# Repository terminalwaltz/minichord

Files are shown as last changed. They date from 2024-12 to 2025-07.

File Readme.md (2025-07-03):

# minichord 

This repository contains the source file both for the minichord itself and its documentation. 

Watch the video (https://www.youtube.com/watch?v=66Gu4NNnHgA)

To be informed about the project, please subscribe to [the newsletter](https://buttondown.com/BenjaminPoilve).

* [#1 project update](https://buttondown.com/BenjaminPoilve/archive/minichord-update-1/) 
* [#2 project update](https://buttondown.com/BenjaminPoilve/archive/minichord-update-2/) 
* [#3 project update and pre-order link](https://buttondown.com/BenjaminPoilve/archive/minichord-update-3/) 
* [#4 project update](https://buttondown.com/BenjaminPoilve/archive/minichord-update-4/) 
* [#5 project update](https://buttondown.com/BenjaminPoilve/archive/minichord-update-5/) 

## Documentation 

The best way to get to know this project is to visit the [minichord website](https://minichord.com/) which contains the documentation of the project. 

In particular it contains:

- the [user manual of the minichord](https://minichord.com/user_manual/)
- the [assembly guide of the minichord](https://minichord.com/assembly/)

This documentation is build with mkdocs and the relevant source and build script is available in the [documentation folder](https://github.com/BenjaminPoilve/MiniChord/tree/main/documentation).

## Hardware 

The hardware folder contains the necessary ressources to build a minichord. 

All hardware is provided under a Creative Commons Attribution-NonCommercial 4.0 International Public
License (CC BY-NC 4.0). 

In particular it contains: 

- the [files necessary to manufacture the PCB](https://github.com/BenjaminPoilve/MiniChord/tree/main/hardware/PCB)
- the [full BOM of the project](https://github.com/BenjaminPoilve/MiniChord/tree/main/hardware/BOM)
- the [3D enclosure files](https://github.com/BenjaminPoilve/MiniChord/tree/main/hardware/3D/rendering)
- the [keycap routing files](https://github.com/BenjaminPoilve/MiniChord/tree/main/hardware/graphics)

## Firmware 

The firmware folder contains the project firmware and necessary programming ressources.

All software is provided under a 3-clause BSD License.

In particular it contains: 
- the [Hex firmware](https://github.com/BenjaminPoilve/MiniChord/blob/main/firmware/firmware.hex)
- the full [PlatformIO project](https://github.com/BenjaminPoilve/MiniChord/tree/main/firmware)
- the [minicontrol software](https://github.com/BenjaminPoilve/MiniChord/tree/main/firmware/minicontrol)

## Media 

Here is a list of available media related to the project (to be completed) :

- a technical video about [the minicontrol system](https://www.youtube.com/watch?v=h-6qkhU_WoA&t=933s)
- a short [audio demo of selected presets](https://minichord.com/ressources/audio_demo.mp3)
- a [review of the project by Hainbach](https://www.youtube.com/watch?v=zQC3umGRGbM)
- an [interview I gave for the launch of the project with SeeedStudio](https://www.youtube.com/watch?v=swZKdO71dLo)
- a [folder of videos from minichord users](https://github.com/BenjaminPoilve/minichord/tree/main/documentation/docs/ressources/video) 

## Contact 

For any information about the project, don't hesitate to write at info@minichord.com

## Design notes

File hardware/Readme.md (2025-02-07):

# Hardware  

This folder contains the necessary ressources to build a minichord. 

### Electronics

* [Main PCB schematics](https://github.com/BenjaminPoilve/MiniChord/blob/main/hardware/PCB/miniChord_main_PCB/MiniChord.pdf)
* [Main PCB Gerber file](https://github.com/BenjaminPoilve/MiniChord/tree/main/hardware/PCB/miniChord_main_PCB/gerber)
* [Touch zone PCB schematics](https://github.com/BenjaminPoilve/MiniChord/blob/main/hardware/PCB/touch%20zones/default%20touch%20PCB/touch_zone.pdf)
* [Touch zone PCB Gerber file](https://github.com/BenjaminPoilve/MiniChord/blob/main/hardware/PCB/touch%20zones/default%20touch%20PCB/gerber)
* [Template for custom touch zone](https://github.com/BenjaminPoilve/MiniChord/blob/main/hardware/PCB/touch%20zones/touch%20kicad%20template)

### BOM

* [Full BOM](https://github.com/BenjaminPoilve/MiniChord/blob/main/hardware/BOM/full_BOM.pdf)

### 3D files

* [Bottom shell](https://github.com/BenjaminPoilve/MiniChord/blob/main/hardware/3D/rendering/render_v9_bottom.scad.stl) 
* [Top shell](https://github.com/BenjaminPoilve/MiniChord/blob/main/hardware/3D/rendering/render_v9_top1_5.scad.stl)

### 2D files 

* [Key engraving](https://github.com/BenjaminPoilve/MiniChord/blob/main/hardware/graphics/key_engraving.svg)

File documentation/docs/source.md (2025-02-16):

# **Software** 

> All software is provided under a 3-clause BSD License

* [minicontrol software](https://github.com/BenjaminPoilve/MiniChord/tree/main/firmware/minicontrol)
* [Hex firmware](https://github.com/BenjaminPoilve/MiniChord/blob/main/firmware/firmware.hex)
* [PlatformIO project](https://github.com/BenjaminPoilve/MiniChord/tree/main/firmware)
* [Tutorial for PlatformIO Teensy usage](https://forum.pjrc.com/index.php?threads/tutorial-how-to-use-platformio-visual-code-studio-for-teensy.66674/)

<hr>

# **Hardware**

> All hardware is provided under a Creative Commons Attribution-NonCommercial 4.0 International Public
License (CC BY-NC 4.0)

## 3D files

* [Bottom shell](https://github.com/BenjaminPoilve/MiniChord/blob/main/hardware/3D/rendering/render_v11_bottom.scad.stl) 
* [Top shell](https://github.com/BenjaminPoilve/MiniChord/blob/main/hardware/3D/rendering/render_v11_top.scad.stl)

## 2D files 

* [Key engraving](https://github.com/BenjaminPoilve/MiniChord/blob/main/hardware/graphics/key_engraving.svg)

## Electronics

* [Full BOM](https://github.com/BenjaminPoilve/MiniChord/blob/main/hardware/BOM/full_BOM.pdf)
* [Main PCB schematics](https://github.com/BenjaminPoilve/MiniChord/blob/main/hardware/PCB/miniChord_main_PCB/MiniChord.pdf)
* [Main PCB Gerber file](https://github.com/BenjaminPoilve/MiniChord/tree/main/hardware/PCB/miniChord_main_PCB/gerber)
* [Touch zone PCB schematics](https://github.com/BenjaminPoilve/MiniChord/blob/main/hardware/PCB/touch%20zones/default%20touch%20PCB/touch_zone.pdf)
* [Touch zone PCB Gerber file](https://github.com/BenjaminPoilve/MiniChord/tree/main/hardware/PCB/touch%20zones/default%20touch%20PCB/gerber)

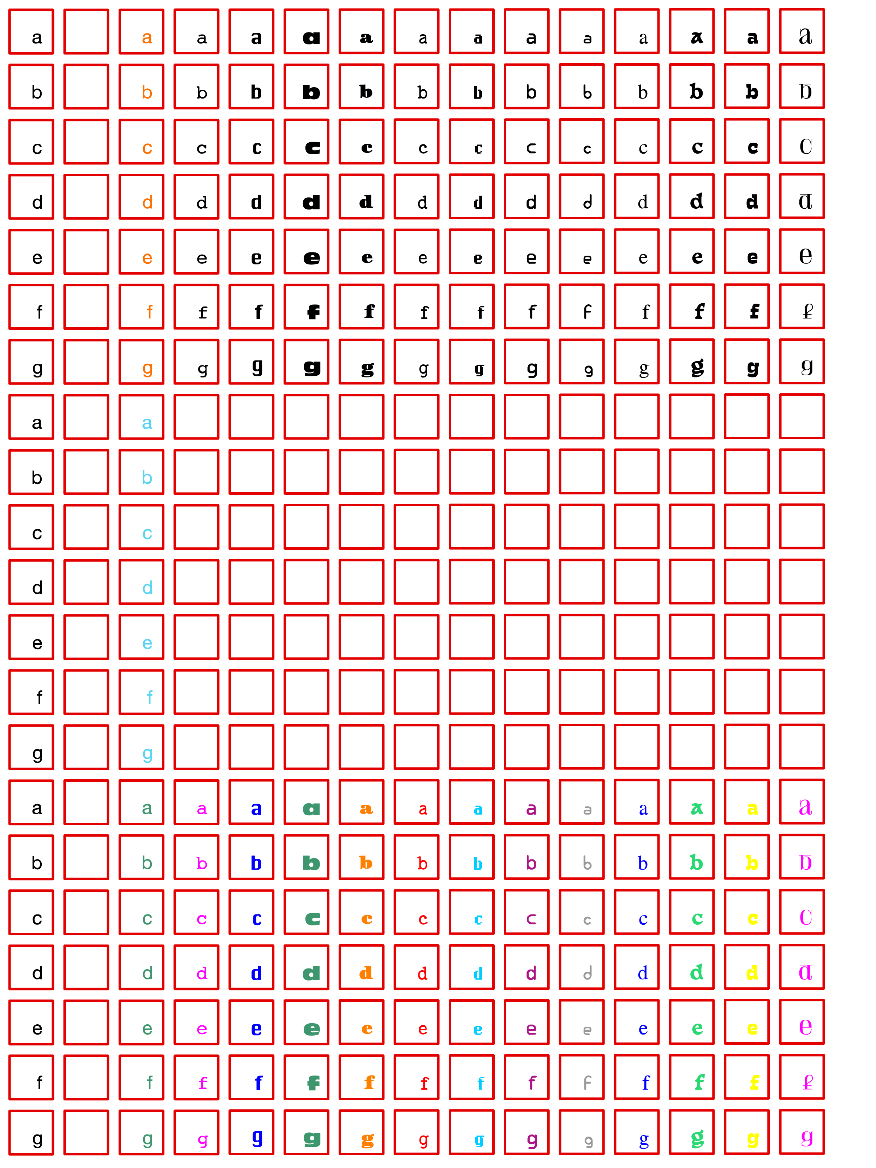
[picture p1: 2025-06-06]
hardware/graphics/DTF_sheet.png

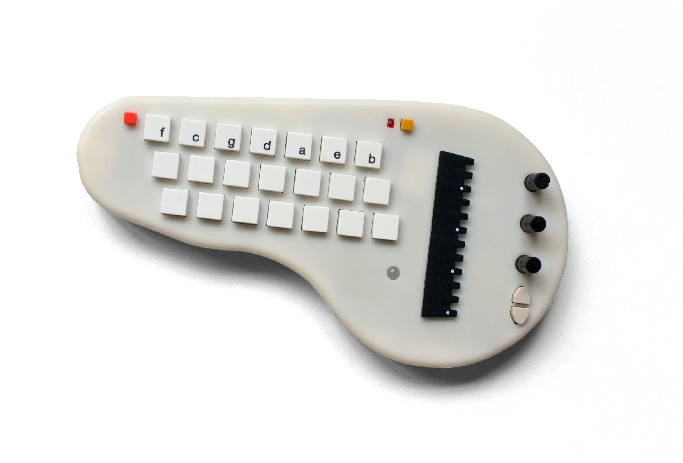
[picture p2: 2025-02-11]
documentation/docs/ressources/hero.webp

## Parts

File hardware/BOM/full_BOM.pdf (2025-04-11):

### Full BOM

Quantity | Part | Type | Link
2 | 1608 10uf capacitor | SMD component
3 | 2012 2.2uf capacitor | SMD component
1 | 6.3x5.7 100uf capacitor | SMD component
1 | 3216 100uf capacitor | SMD component
8 | 1608 100nf capacitor | SMD component
1 | 4x5.4 10uf capacitor | SMD component
2 | 1608 2.2nf capacitor | SMD component
1 | 2012 4.7uf capacitor | SMD component
1 | side mount bicolour led | SMD component
1 | SWPA60 6.8uH inductor | SMD component
1 | 2012 1k resistor | SMD component
1 | 1608 330k resistor | SMD component
1 | 2012 680 resistor | SMD component
2 | 1608 1.8M resistor | SMD component
1 | 1608 220k resistor | SMD component
1 | 1608 1M resistor | SMD component
1 | 2012 2k resistor | SMD component
2 | 2012 2k2 resistor | SMD component
8 | 2012 10k resistor | SMD component
1 | 1608 75k resistor | SMD component
4 | 1608 22 resistor | SMD component
1 | 1608 560 resistor | SMD component
1 | 1608 100 resistor | SMD component
1 | 1608 200 resistor | SMD component
3 | 1608 470 resistor | SMD component
1 | PVQFN TPS61090 | SMD component
1 | SOT-23 MCP73831 | SMD component
1 | SOIC-16 74HC595 | SMD component
1 | TSSOP-20 PCM5102 | SMD component
1 | UQFN-20 MPR121QR2 | SMD component
8 | 1N4148WT | SMD component
1 | Red LED | TH component | Mouser (https://www.mouser.fr/ProductDetail/604-WP169XID)
1 | 5mm RKGB LED | TH component | -
1 | Switched Audio Jack | TH component | Mouser (https://www.mouser.fr/ProductDetail/490-SJ-3566AN)
1 | JST PH 2mm 2pin male angled | TH component | -
1 | 503450 1000mAh battery | other hardware | -
3 | Potentiometer | TH component | Mouser (https://www.mouser.fr/ProductDetail/317-2090F-100K) (note: if we could source a RV09AF-40-15K-B100K instead, it would be better)
2 | Tactile switch 6x6mm | TH component | Mouser (https://www.mouser.fr/ProductDetail/653-B3F-1050)
21 | Tactile switch 12x12mm | TH component | Mouser (https://www.mouser.fr/ProductDetail/653-B3F-4050)
2 | Touch header female | TH component | Mouser (https://www.mouser.fr/ProductDetail/855-M20-7810345R)
2 | Touch header male | TH component | Mouser (https://www.mouser.fr/ProductDetail/855-M20-8760346)
1 | Teensy 4.0 | TH component | PJRC (https://www.pjrc.com/store/teensy40.html)
1 | Teensy headers | TH component | Mouser (https://www.mouser.fr/ProductDetail/Samtec/TSW-132-06-T-S?qs=rU5fayqh%252BE1E2ITYQW/0SQ==)
21 | Tactile switch keycap 9x9 | other hardware | Mouser (https://www.mouser.fr/ProductDetail/653-B32-1260)
2 | Tactile switch keycap key top | other hardware | Mouser (https://www.mouser.fr/ProductDetail/653-B322100)
1 | Tactile switch keycap 4x4 orange | other hardware | Mouser (https://www.mouser.fr/ProductDetail/653-B32-1020)

1

Quantity | Part | Type | Link
1 | Tactile switch keycap 4x4 yellow | other hardware | Mouser (https://www.mouser.fr/ProductDetail/653-B32-1030)
1 | Top shell | other hardware | -
1 | Bottom shell | other hardware | -
1 | Double sided tape | other hardware | -
6 | M2.3x8 self taping screws | other hardware | -
3 | M2.3x6 self taping screws | other hardware | -

2

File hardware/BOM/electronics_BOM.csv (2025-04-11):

Reference | Value | Link | Footprint | Qty | DNP | Description
C1 | 10uf | https://www.lcsc.com/product-detail/Multilayer-Ceramic-Capacitors-MLCC-SMD-SMT_Samsung-Electro-Mechanics-CL10A106MA8NRNC_C96446.html | Capacitor_SMD:C_0603_1608Metric | 1
C2 | 10uf | https://www.lcsc.com/product-detail/Multilayer-Ceramic-Capacitors-MLCC-SMD-SMT_Samsung-Electro-Mechanics-CL10A106MA8NRNC_C96446.html | Capacitor_SMD:C_0603_1608Metric | 1
C3 | 100n | https://www.lcsc.com/product-detail/Multilayer-Ceramic-Capacitors-MLCC-SMD-SMT_YAGEO-CC0603KRX7R9BB104_C14663.html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 | Capacitor_SMD:C_0603_1608Metric | 1
C4 | 2.2uf | https://www.lcsc.com/product-detail/Multilayer-Ceramic-Capacitors-MLCC-SMD-SMT_Samsung-Electro-Mechanics-CL21A225KBQNNNE_C377773.html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 | Capacitor_SMD:C_0805_2012Metric | 1
C5 | 100uf | https://www.lcsc.com/product-detail/Aluminum-Electrolytic-Capacitors-SMD_Capxon-International-Elec-HV101M6R3E055ETR_C65235.html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 | Capacitor_SMD:CP_Elec_6.3x5.7 | 1
C6 | 100uf | https://www.lcsc.com/product-detail/Multilayer-Ceramic-Capacitors-MLCC-SMD-SMT_Samsung-Electro-Mechanics-CL31A107MQHNNNE_C15008.html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 | Capacitor_SMD:C_1206_3216Metric | 1
C7 | 100n | https://www.lcsc.com/product-detail/Multilayer-Ceramic-Capacitors-MLCC-SMD-SMT_YAGEO-CC0603KRX7R9BB104_C14663.html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 | Capacitor_SMD:C_0603_1608Metric | 1
C8 | 100n | https://www.lcsc.com/product-detail/Multilayer-Ceramic-Capacitors-MLCC-SMD-SMT_YAGEO-CC0603KRX7R9BB104_C14663.html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 | Capacitor_SMD:C_0603_1608Metric | 1
C9 | 2.2uf | https://www.lcsc.com/product-detail/Multilayer-Ceramic-Capacitors-MLCC-SMD-SMT_Samsung-Electro-Mechanics-CL21A225KBQNNNE_C377773.html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 | Capacitor_SMD:C_0805_2012Metric | 1
C10 | 2.2uf | https://www.lcsc.com/product-detail/Multilayer-Ceramic-Capacitors-MLCC-SMD-SMT_Samsung-Electro-Mechanics-CL21A225KBQNNNE_C377773.html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 | Capacitor_SMD:C_0805_2012Metric | 1
C11 | 100n | https://www.lcsc.com/product-detail/Multilayer-Ceramic-Capacitors-MLCC-SMD-SMT_YAGEO-CC0603KRX7R9BB104_C14663.html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 | Capacitor_SMD:C_0603_1608Metric | 1
C12 | 100n | https://www.lcsc.com/product-detail/Multilayer-Ceramic-Capacitors-MLCC-SMD-SMT_YAGEO-CC0603KRX7R9BB104_C14663.html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 | Capacitor_SMD:C_0603_1608Metric | 1
C13 | 100n | https://www.lcsc.com/product-detail/Multilayer-Ceramic-Capacitors-MLCC-SMD-SMT_YAGEO-CC0603KRX7R9BB104_C14663.html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 | Capacitor_SMD:C_0603_1608Metric | 1
C14 | 100n | https://www.lcsc.com/product-detail/Multilayer-Ceramic-Capacitors-MLCC-SMD-SMT_YAGEO-CC0603KRX7R9BB104_C14663.html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 | Capacitor_SMD:C_0603_1608Metric | 1
C15 | 10uf | https://www.lcsc.com/product-detail/Aluminum-Electrolytic-Capacitors-SMD_KNSCHA-126RV0157_C7461288.html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 | Capacitor_SMD:CP_Elec_4x5.4 | 1
C16 | 2.2nf | https://www.lcsc.com/product-detail/Multilayer-Ceramic-Capacitors-MLCC-SMD-SMT_FH-Guangdong-Fenghua-Advanced-Tech-0603B222K500NT_C1604.html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 | Capacitor_SMD:C_0603_1608Metric | 1
C17 | 2.2nf | https://www.lcsc.com/product-detail/Multilayer-Ceramic-Capacitors-MLCC-SMD-SMT_FH-Guangdong-Fenghua-Advanced-Tech-0603B222K500NT_C1604.html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 | Capacitor_SMD:C_0603_1608Metric | 1
C18 | 4.7uf | https://www.lcsc.com/product-detail/Multilayer-Ceramic-Capacitors-MLCC-SMD-SMT_Samsung-Electro-Mechanics-CL21A475KAQNNNE_C1779.html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 | Capacitor_SMD:C_0805_2012Metric | 1
C19 | 100n | https://www.lcsc.com/product-detail/Multilayer-Ceramic-Capacitors-MLCC-SMD-SMT_YAGEO-CC0603KRX7R9BB104_C14663.html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 | Capacitor_SMD:C_0603_1608Metric | 1
D1 | LED | https://www.mouser.fr/ProductDetail/Kingbright/WP169XID?qs=DkZGzo4b%252BTI3yOiggkw3fg%3D%3D | Personnal_Library:WP169XID | 1
D2 | LED_RKGB | https://fr.aliexpress.com/item/1005004567358995.html | Personnal_Library:LED_D5.0mm-4_RGB-cutout | 1
D3 | LED_Dual_AAKK | https://www.lcsc.com/product-detail/LED-Indication-Discrete_Amicc-A-SP1102AR6GHC-A01-2C_C5160724.html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 | Personnal_Library:R_G side led | 1
D4 | 1N4148WT | https://www.lcsc.com/product-detail/Switching-Diodes_hongjiacheng-1N4148WT_C7420320.html?s_z=n_C7420320 | Diode_SMD:D_SOD-523 | 1
D5 | 1N4148WT | https://www.lcsc.com/product-detail/Switching-Diodes_hongjiacheng-1N4148WT_C7420320.html?s_z=n_C7420320 | Diode_SMD:D_SOD-523 | 1
D6 | 1N4148WT | https://www.lcsc.com/product-detail/Switching-Diodes_hongjiacheng-1N4148WT_C7420320.html?s_z=n_C7420320 | Diode_SMD:D_SOD-523 | 1
D7 | 1N4148WT | https://www.lcsc.com/product-detail/Switching-Diodes_hongjiacheng-1N4148WT_C7420320.html?s_z=n_C7420320 | Diode_SMD:D_SOD-523 | 1
D8 | 1N4148WT | https://www.lcsc.com/product-detail/Switching-Diodes_hongjiacheng-1N4148WT_C7420320.html?s_z=n_C7420320 | Diode_SMD:D_SOD-523 | 1
D9 | 1N4148WT | https://www.lcsc.com/product-detail/Switching-Diodes_hongjiacheng-1N4148WT_C7420320.html?s_z=n_C7420320 | Diode_SMD:D_SOD-523 | 1
D10 | 1N4148WT | https://www.lcsc.com/product-detail/Switching-Diodes_hongjiacheng-1N4148WT_C7420320.html?s_z=n_C7420320 | Diode_SMD:D_SOD-523 | 1
D11 | 1N4148WT | https://www.lcsc.com/product-detail/Switching-Diodes_hongjiacheng-1N4148WT_C7420320.html?s_z=n_C7420320 | Diode_SMD:D_SOD-523 | 1
J1 | Conn_02x03_Top_Bottom | https://www.mouser.fr/ProductDetail/Harwin/M20-7810345R?qs=k41KVqW3ymoME5l5QJ2Feg%3D%3D | Personnal_Library:03x02 bottom entry header | 1
J2 | AudioJack_switched | https://www.mouser.fr/ProductDetail/Same-Sky/SJ-3566AN?qs=WyjlAZoYn52HouuVvH6sjg%3D%3D | Personnal_Library:Switched Jack PJ307_3525 | 1
J3 | Conn_01x02 | https://www.lcsc.com/product-detail/Wire-To-Board-Connector_JST-S2B-PH-K-S-LF-SN_C173752.html?s_z=n_JST%20PH | Connector_JST:JST_PH_S2B-PH-K_1x02_P2.00mm_Horizontal | 1
J4 | Conn_02x03_Top_Bottom | https://www.mouser.fr/ProductDetail/Harwin/M20-7810345R?qs=k41KVqW3ymoME5l5QJ2Feg%3D%3D | Personnal_Library:03x02 bottom entry header | 1
L1 | 6.8uH | https://www.digikey.fr/en/products/detail/shenzhen-sunlord-electronics-co-ltd/SWPA6045S6R8MT/14119994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 | Inductor_SMD:L_Sunlord_SWPA60xxS | 1
R1 | 1k | https://www.lcsc.com/product-detail/Chip-Resistor-Surface-Mount_UNI-ROYAL-Uniroyal-Elec-0805W8F1001T5E_C17513.html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 | Resistor_SMD:R_0805_2012Metric | 1
R2 | 1.8M | https://www.lcsc.com/product-detail/Chip-Resistor-Surface-Mount_FOJAN-FRC0603F1804TS_C2933162.html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 | Resistor_SMD:R_0603_1608Metric | 1
R3 | 330k | https://www.lcsc.com/product-detail/Chip-Resistor-Surface-Mount_UNI-ROYAL-Uniroyal-Elec-0603WAF3303T5E_C23137.html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 | Resistor_SMD:R_0603_1608Metric | 1
R4 | 680 | https://www.lcsc.com/product-detail/Chip-Resistor-Surface-Mount_UNI-ROYAL-Uniroyal-Elec-0805W8F6800T5E_C17798.html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 | Resistor_SMD:R_0805_2012Metric | 1
R5 | 1.8M | https://www.lcsc.com/product-detail/Chip-Resistor-Surface-Mount_FOJAN-FRC0603F1804TS_C2933162.html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 | Resistor_SMD:R_0603_1608Metric | 1
R6 | 220k | https://www.lcsc.com/product-detail/Chip-Resistor-Surface-Mount_UNI-ROYAL-Uniroyal-Elec-0603WAF2203T5E_C22961.html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 | Resistor_SMD:R_0603_1608Metric | 1
R7 | 1M | https://www.lcsc.com/product-detail/Chip-Resistor-Surface-Mount_UNI-ROYAL-Uniroyal-Elec-0603WAF1004T5E_C22935.html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 | Resistor_SMD:R_0603_1608Metric | 1
R8 | 2k | https://www.lcsc.com/product-detail/Chip-Resistor-Surface-Mount_UNI-ROYAL-Uniroyal-Elec-0805W8F2001T5E_C17604.html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 | Resistor_SMD:R_0805_2012Metric | 1
R9 | 2k2 | https://www.lcsc.com/product-detail/Chip-Resistor-Surface-Mount_UNI-ROYAL-Uniroyal-Elec-0805W8F2201T5E_C17520.html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 | Resistor_SMD:R_0805_2012Metric | 1
R10 | 2k2 | https://www.lcsc.com/product-detail/Chip-Resistor-Surface-Mount_UNI-ROYAL-Uniroyal-Elec-0805W8F2201T5E_C17520.html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 | Resistor_SMD:R_0805_2012Metric | 1
R11 | 10k | https://www.lcsc.com/product-detail/Chip-Resistor-Surface-Mount_UNI-ROYAL-Uniroyal-Elec-0805W8F1002T5E_C17414.html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 | Resistor_SMD:R_0805_2012Metric | 1
R12 | 10k | https://www.lcsc.com/product-detail/Chip-Resistor-Surface-Mount_UNI-ROYAL-Uniroyal-Elec-0805W8F1002T5E_C17414.html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 | Resistor_SMD:R_0805_2012Metric | 1
R13 | 10k | https://www.lcsc.com/product-detail/Chip-Resistor-Surface-Mount_UNI-ROYAL-Uniroyal-Elec-0805W8F1002T5E_C17414.html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 | Resistor_SMD:R_0805_2012Metric | 1
R14 | 10k | https://www.lcsc.com/product-detail/Chip-Resistor-Surface-Mount_UNI-ROYAL-Uniroyal-Elec-0805W8F1002T5E_C17414.html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 | Resistor_SMD:R_0805_2012Metric | 1
R15 | 75k | https://www.lcsc.com/product-detail/Chip-Resistor-Surface-Mount_UNI-ROYAL-Uniroyal-Elec-0603WAF7502T5E_C23242.html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 | Resistor_SMD:R_0603_1608Metric | 1
R16 | 10k | https://www.lcsc.com/product-detail/Chip-Resistor-Surface-Mount_UNI-ROYAL-Uniroyal-Elec-0805W8F1002T5E_C17414.html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 | Resistor_SMD:R_0805_2012Metric | 1
R27 | 22 | https://www.lcsc.com/product-detail/Chip-Resistor-Surface-Mount_UNI-ROYAL-Uniroyal-Elec-0603WAF220JT5E_C23345.html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 | Resistor_SMD:R_0603_1608Metric | 1
R28 | 22 | https://www.lcsc.com/product-detail/Chip-Resistor-Surface-Mount_UNI-ROYAL-Uniroyal-Elec-0603WAF220JT5E_C23345.html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 | Resistor_SMD:R_0603_1608Metric | 1
R29 | 22 | https://www.lcsc.com/product-detail/Chip-Resistor-Surface-Mount_UNI-ROYAL-Uniroyal-Elec-0603WAF220JT5E_C23345.html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 | Resistor_SMD:R_0603_1608Metric | 1
R30 | 22 | https://www.lcsc.com/product-detail/Chip-Resistor-Surface-Mount_UNI-ROYAL-Uniroyal-Elec-0603WAF220JT5E_C23345.html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 | Resistor_SMD:R_0603_1608Metric | 1
R31 | 470 | https://www.lcsc.com/product-detail/Chip-Resistor-Surface-Mount_UNI-ROYAL-Uniroyal-Elec-0603WAF4700T5E_C23179.html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 | Resistor_SMD:R_0603_1608Metric | 1
R32 | 470 | https://www.lcsc.com/product-detail/Chip-Resistor-Surface-Mount_UNI-ROYAL-Uniroyal-Elec-0603WAF4700T5E_C23179.html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 | Resistor_SMD:R_0603_1608Metric | 1
R34 | 560 | https://www.lcsc.com/product-detail/Chip-Resistor-Surface-Mount_UNI-ROYAL-Uniroyal-Elec-0603WAF5600T5E_C23204.html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 | Resistor_SMD:R_0603_1608Metric | 1
R35 | 100 | https://www.lcsc.com/product-detail/Chip-Resistor-Surface-Mount_UNI-ROYAL-Uniroyal-Elec-0603WAF1000T5E_C22775.html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 | Resistor_SMD:R_0603_1608Metric | 1
R36 | 200 | https://www.lcsc.com/product-detail/Chip-Resistor-Surface-Mount_UNI-ROYAL-Uniroyal-Elec-0603WAF2000T5E_C8218.html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 | Resistor_SMD:R_0603_1608Metric | 1
R37 | 470 | https://www.lcsc.com/product-detail/Chip-Resistor-Surface-Mount_UNI-ROYAL-Uniroyal-Elec-0603WAF4700T5E_C23179.html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 | Resistor_SMD:R_0603_1608Metric | 1
R38 | 10k | https://www.lcsc.com/product-detail/Chip-Resistor-Surface-Mount_UNI-ROYAL-Uniroyal-Elec-0805W8F1002T5E_C17414.html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 | Resistor_SMD:R_0805_2012Metric | 1
R39 | 10k | https://www.lcsc.com/product-detail/Chip-Resistor-Surface-Mount_UNI-ROYAL-Uniroyal-Elec-0805W8F1002T5E_C17414.html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 | Resistor_SMD:R_0805_2012Metric | 1
R40 | 10k | https://www.lcsc.com/product-detail/Chip-Resistor-Surface-Mount_UNI-ROYAL-Uniroyal-Elec-0805W8F1002T5E_C17414.html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 | Resistor_SMD:R_0805_2012Metric | 1
RV1 | 100k | https://www.mouser.fr/ProductDetail/Alpha-Taiwan/RV09AF-40-20K-B100K?qs=eadLBtAAYOcDATbz39dQgg%3D%3D | Personnal_Library:Alpha B100k_deep | 1
RV2 | 100k | https://www.mouser.fr/ProductDetail/Alpha-Taiwan/RV09AF-40-20K-B100K?qs=eadLBtAAYOcDATbz39dQgg%3D%3D | Personnal_Library:Alpha B100k_deep | 1
RV3 | 100k | https://www.mouser.fr/ProductDetail/Alpha-Taiwan/RV09AF-40-20K-B100K?qs=eadLBtAAYOcDATbz39dQgg%3D%3D | Personnal_Library:Alpha B100k_deep | 1
SW1 | SW_12mm | https://www.mouser.fr/ProductDetail/Omron-Electronics/B3F-4050?qs=B3tblJ0Nlt9ObBVoLmesBQ%3D%3D | Personnal_Library:OMRON B3F-40 | 1
SW2 | SW_12mm | https://www.mouser.fr/ProductDetail/Omron-Electronics/B3F-4050?qs=B3tblJ0Nlt9ObBVoLmesBQ%3D%3D | Personnal_Library:OMRON B3F-40 | 1
SW3 | SW_12mm | https://www.mouser.fr/ProductDetail/Omron-Electronics/B3F-4050?qs=B3tblJ0Nlt9ObBVoLmesBQ%3D%3D | Personnal_Library:OMRON B3F-40 | 1
SW4 | SW_12mm | https://www.mouser.fr/ProductDetail/Omron-Electronics/B3F-4050?qs=B3tblJ0Nlt9ObBVoLmesBQ%3D%3D | Personnal_Library:OMRON B3F-40 | 1
SW5 | SW_12mm | https://www.mouser.fr/ProductDetail/Omron-Electronics/B3F-4050?qs=B3tblJ0Nlt9ObBVoLmesBQ%3D%3D | Personnal_Library:OMRON B3F-40 | 1
SW6 | SW_12mm | https://www.mouser.fr/ProductDetail/Omron-Electronics/B3F-4050?qs=B3tblJ0Nlt9ObBVoLmesBQ%3D%3D | Personnal_Library:OMRON B3F-40 | 1
SW7 | SW_12mm | https://www.mouser.fr/ProductDetail/Omron-Electronics/B3F-4050?qs=B3tblJ0Nlt9ObBVoLmesBQ%3D%3D | Personnal_Library:OMRON B3F-40 | 1
SW8 | SW_12mm | https://www.mouser.fr/ProductDetail/Omron-Electronics/B3F-4050?qs=B3tblJ0Nlt9ObBVoLmesBQ%3D%3D | Personnal_Library:OMRON B3F-40 | 1
SW9 | SW_12mm | https://www.mouser.fr/ProductDetail/Omron-Electronics/B3F-4050?qs=B3tblJ0Nlt9ObBVoLmesBQ%3D%3D | Personnal_Library:OMRON B3F-40 | 1
SW10 | SW_12mm | https://www.mouser.fr/ProductDetail/Omron-Electronics/B3F-4050?qs=B3tblJ0Nlt9ObBVoLmesBQ%3D%3D | Personnal_Library:OMRON B3F-40 | 1
SW11 | SW_12mm | https://www.mouser.fr/ProductDetail/Omron-Electronics/B3F-4050?qs=B3tblJ0Nlt9ObBVoLmesBQ%3D%3D | Personnal_Library:OMRON B3F-40 | 1
SW12 | SW_12mm | https://www.mouser.fr/ProductDetail/Omron-Electronics/B3F-4050?qs=B3tblJ0Nlt9ObBVoLmesBQ%3D%3D | Personnal_Library:OMRON B3F-40 | 1
SW13 | SW_12mm | https://www.mouser.fr/ProductDetail/Omron-Electronics/B3F-4050?qs=B3tblJ0Nlt9ObBVoLmesBQ%3D%3D | Personnal_Library:OMRON B3F-40 | 1
SW14 | SW_12mm | https://www.mouser.fr/ProductDetail/Omron-Electronics/B3F-4050?qs=B3tblJ0Nlt9ObBVoLmesBQ%3D%3D | Personnal_Library:OMRON B3F-40 | 1
SW15 | SW_12mm | https://www.mouser.fr/ProductDetail/Omron-Electronics/B3F-4050?qs=B3tblJ0Nlt9ObBVoLmesBQ%3D%3D | Personnal_Library:OMRON B3F-40 | 1
SW16 | SW_12mm | https://www.mouser.fr/ProductDetail/Omron-Electronics/B3F-4050?qs=B3tblJ0Nlt9ObBVoLmesBQ%3D%3D | Personnal_Library:OMRON B3F-40 | 1
SW17 | SW_12mm | https://www.mouser.fr/ProductDetail/Omron-Electronics/B3F-4050?qs=B3tblJ0Nlt9ObBVoLmesBQ%3D%3D | Personnal_Library:OMRON B3F-40 | 1
SW18 | SW_12mm | https://www.mouser.fr/ProductDetail/Omron-Electronics/B3F-4050?qs=B3tblJ0Nlt9ObBVoLmesBQ%3D%3D | Personnal_Library:OMRON B3F-40 | 1
SW19 | SW_12mm | https://www.mouser.fr/ProductDetail/Omron-Electronics/B3F-4050?qs=B3tblJ0Nlt9ObBVoLmesBQ%3D%3D | Personnal_Library:OMRON B3F-40 | 1
SW20 | SW_12mm | https://www.mouser.fr/ProductDetail/Omron-Electronics/B3F-4050?qs=B3tblJ0Nlt9ObBVoLmesBQ%3D%3D | Personnal_Library:OMRON B3F-40 | 1
SW21 | SW_12mm | https://www.mouser.fr/ProductDetail/Omron-Electronics/B3F-4050?qs=B3tblJ0Nlt9ObBVoLmesBQ%3D%3D | Personnal_Library:OMRON B3F-40 | 1
SW24 | SW_12mm | https://www.mouser.fr/ProductDetail/Omron-Electronics/B3F-1050?qs=CX134%252BdLMDHtBADdp1bBBw%3D%3D | Personnal_Library:OMRON B3F-10 ARROW | 1
SW25 | SW_12mm | https://www.mouser.fr/ProductDetail/Omron-Electronics/B3F-1050?qs=CX134%252BdLMDHtBADdp1bBBw%3D%3D | Personnal_Library:OMRON B3F-10 ARROW | 1
SW26 | SW_12mm | https://www.mouser.fr/ProductDetail/Omron-Electronics/B3F-1050?qs=CX134%252BdLMDHtBADdp1bBBw%3D%3D | Personnal_Library:OMRON B3F-10 SQUARE | 1
U1 | num | https://www.pjrc.com/store/teensy40.html | Personnal_Library:Teensy40_lite_back | 1
U2 | TPS61090 | https://www.lcsc.com/product-detail/DC-DC-Converters_Texas-Instruments-TPS61090RSAR_C206167.html?s_z=n_C206167 | Package_DFN_QFN:Texas_S-PVQFN-N16_EP2.7x2.7mm_ThermalVias | 1
U3 | MCP73831-2-OT | https://www.lcsc.com/product-detail/Battery-Management_Microchip-Tech-MCP73831T-2ACI-OT_C424093.html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 | Package_TO_SOT_SMD:SOT-23-5 | 1
U4 | 74HC595 | https://www.lcsc.com/product-detail/Shift-Registers_Nexperia-74HC595D-118_C5947.html?s_z=n_C5947 | Package_SO:SOIC-16_3.9x9.9mm_P1.27mm | 1
U5 | PCM5102 | https://www.lcsc.com/product-detail/ADCs-DACs-Special-Purpose_Texas-Instruments-PCM5102APWR_C107671.html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 | Package_SO:TSSOP-20_4.4x6.5mm_P0.65mm | 1
U6 | MPR121QR2 | https://www.lcsc.com/product-detail/Touch-Sensors_NXP-Semicon-MPR121QR2_C91322.html?s_z=n_C91322 | Package_DFN_QFN:UQFN-20_3x3mm_P0.4mm | 1

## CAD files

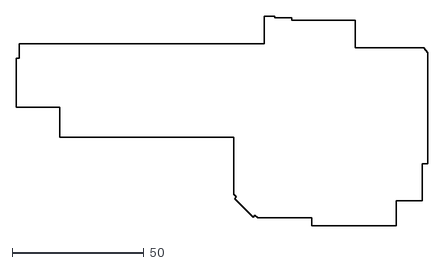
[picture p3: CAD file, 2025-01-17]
hardware/3D/DXF/MiniChord-User_top_component_clearance.dxf
156.0 x 79.5

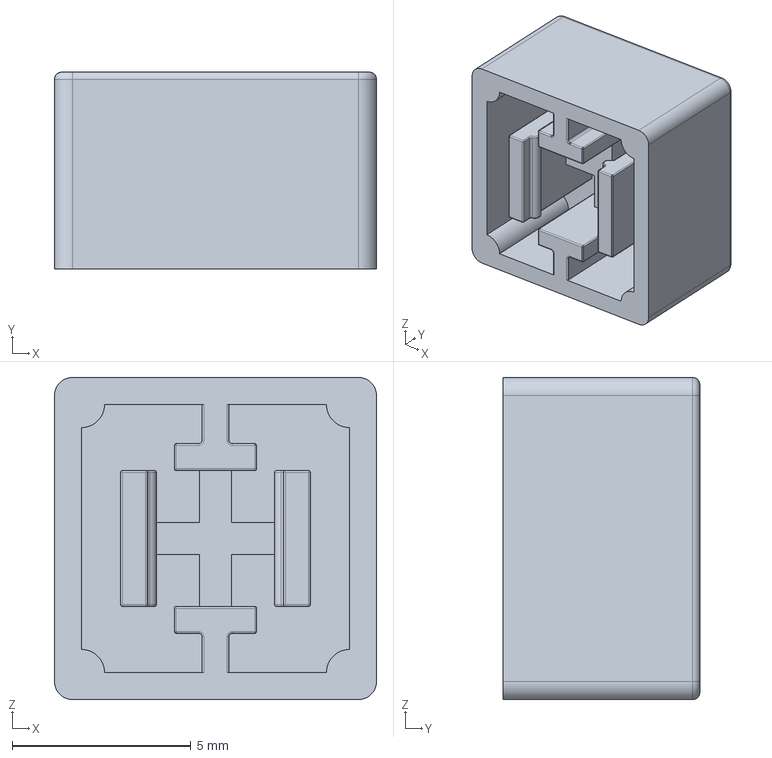
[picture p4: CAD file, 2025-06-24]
hardware/3D/keycaps/keycap.stp
9.00 x 5.50 x 9.00 mm

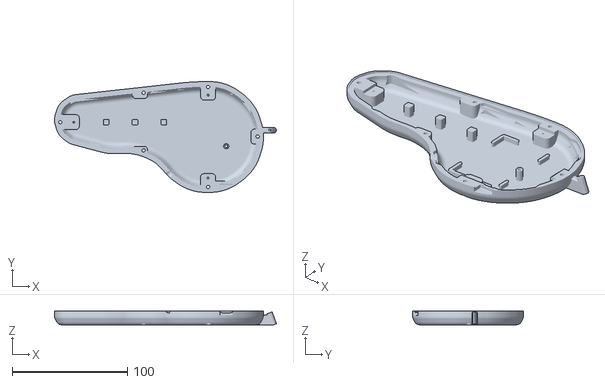
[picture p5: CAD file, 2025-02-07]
hardware/3D/rendering/render_v11_bottom_camera_holder.stl
192.7 x 96.2 x 11.8

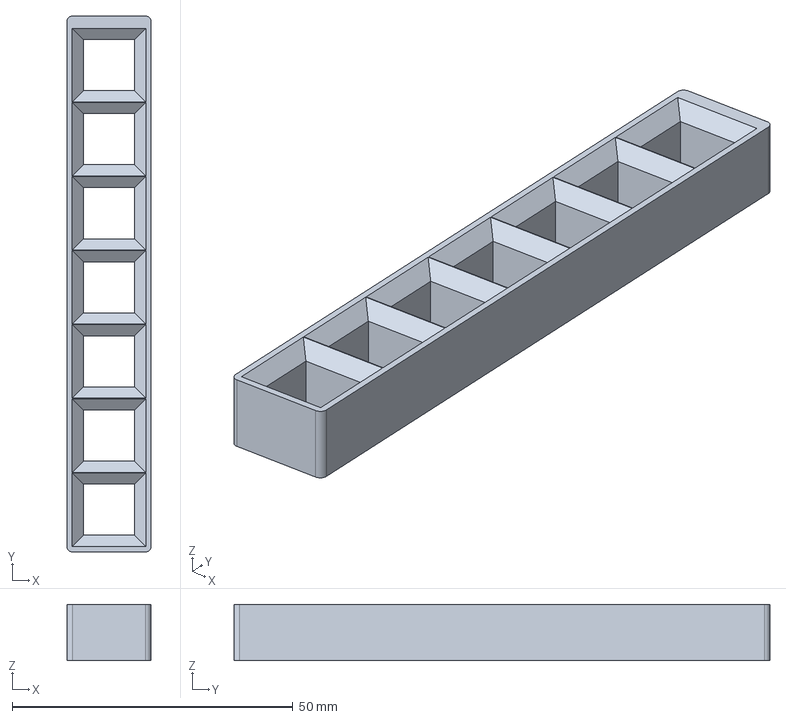
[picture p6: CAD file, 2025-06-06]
hardware/graphics/guide_sticker.FCStd
15.0 x 95.5 x 10.0 mm

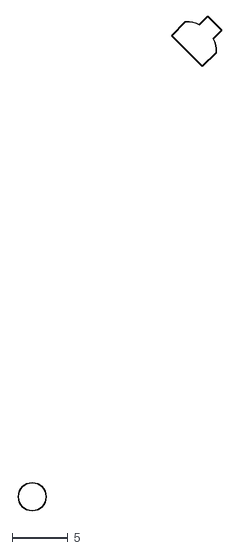
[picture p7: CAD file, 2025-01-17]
hardware/3D/DXF/MiniChord-User_led_clearance.dxf
18.2 x 44.4

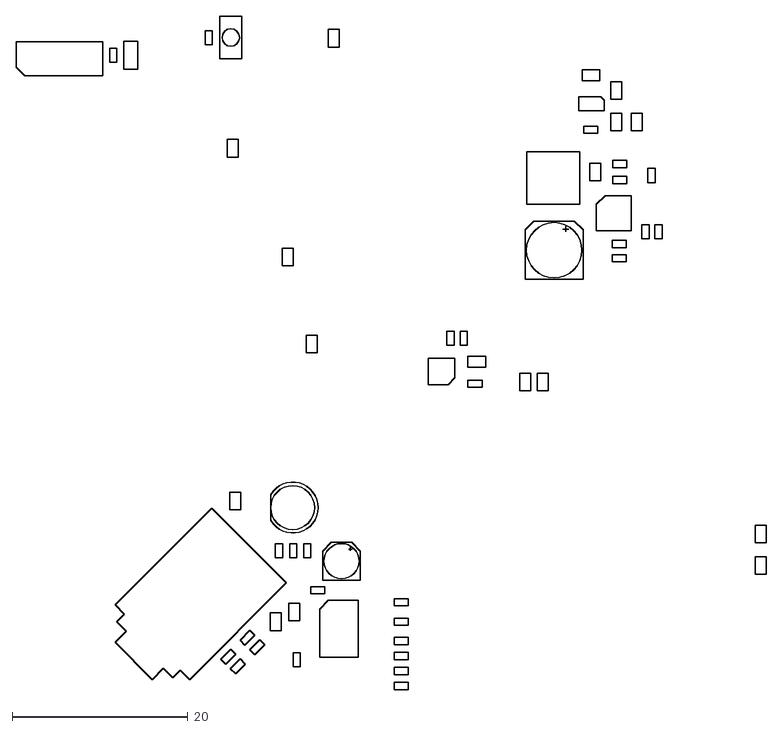
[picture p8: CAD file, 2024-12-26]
hardware/3D/DXF/MiniChord-F_Fab.dxf
85.4 x 76.6

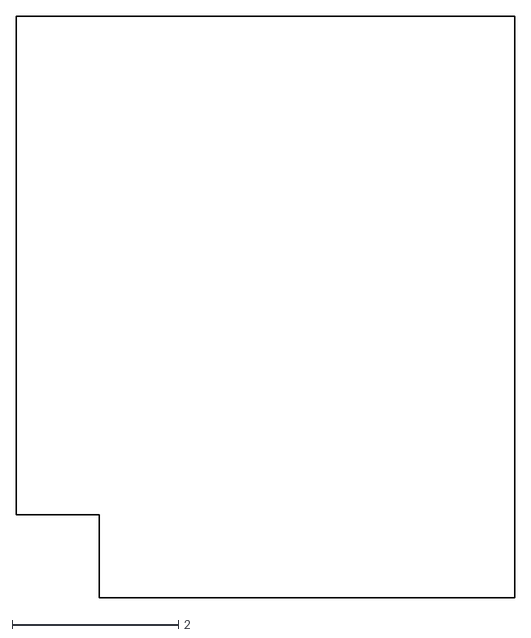
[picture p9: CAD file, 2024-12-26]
hardware/3D/DXF/MiniChord-User_bottom_edge_curve.dxf
6.00 x 7.00

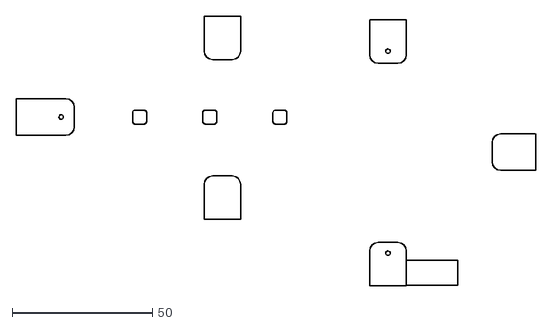
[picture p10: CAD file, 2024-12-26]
hardware/3D/DXF/MiniChord-User_pcb_support.dxf
185.2 x 96.2

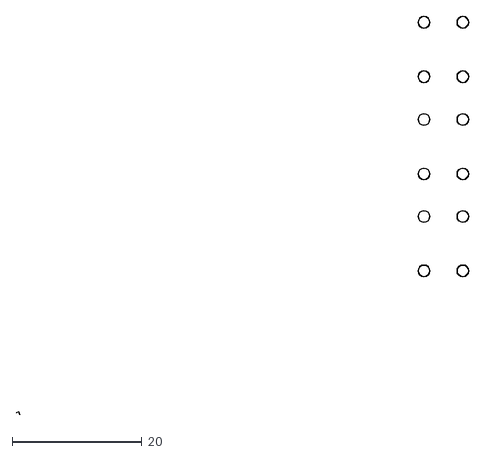
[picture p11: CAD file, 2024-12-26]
hardware/3D/DXF/MiniChord-User_Drawings.dxf
69.8 x 61.5

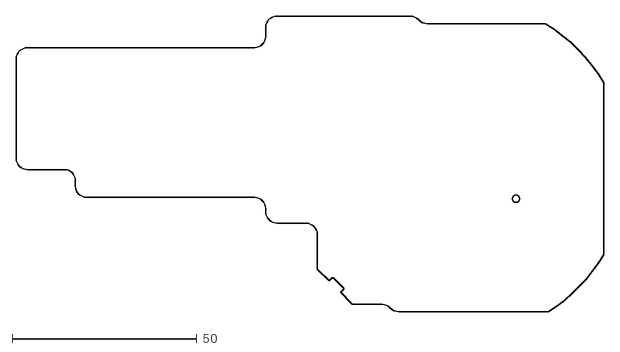
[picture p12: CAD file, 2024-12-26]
hardware/3D/DXF/MiniChord-Edge_Cuts.dxf
159.0 x 80.0

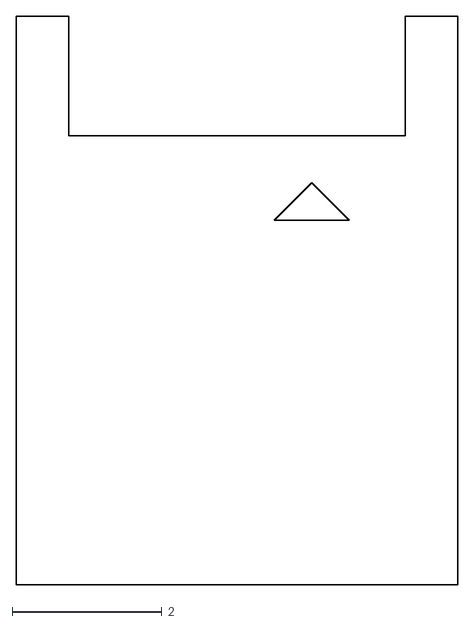
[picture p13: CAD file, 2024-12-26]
hardware/3D/DXF/MiniChord-B_Fab.dxf
5.90 x 7.60

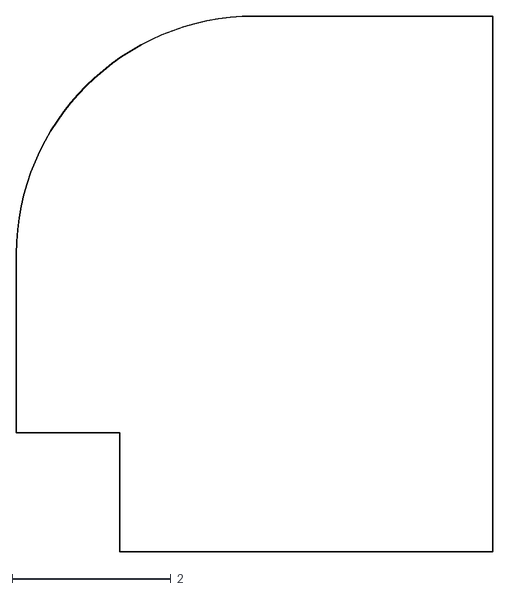
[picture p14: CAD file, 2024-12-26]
hardware/3D/DXF/MiniChord-User_top_edge_curve.dxf
6.00 x 6.75

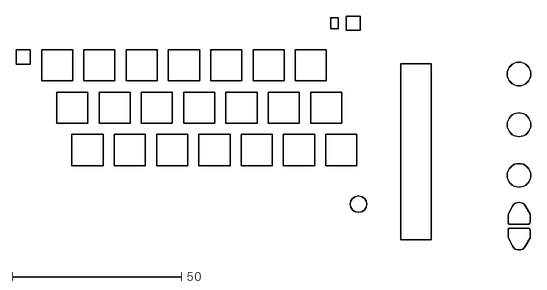
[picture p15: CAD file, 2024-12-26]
hardware/3D/DXF/MiniChord-User_front_plate_cutout.dxf
152.1 x 69.1

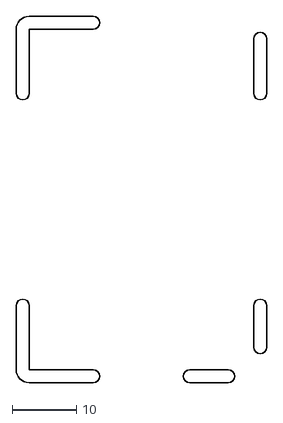
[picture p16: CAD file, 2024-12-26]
hardware/3D/DXF/MiniChord-User_battery_holder.dxf
39.0 x 57.0

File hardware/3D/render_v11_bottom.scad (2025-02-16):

$fn=10;

// The profile is 19.5 in height and 6mm in width
profile_height=17.5;
profile_width=6;

// Keep at 10 for developping, 100 for rendering 
fn_base=80;

// Geometric Parameters   
profile_added_offset=1.5;
plastic_thickness=1.5;
pcb_top_clearance=5.7;
pcb_bottom_clearance=4;
pcb_thickness=1.6;
//The PCB needs a 7.5mm clearance from the top interior of the shell
pcb_depth=pcb_top_clearance+pcb_thickness;

module body(offset=0,fn_body,target_curve){
    //building the body by sliding the profile around
    minkowski() {
            linear_extrude(height = 0.001, center = false, convexity = 20)offset(r=offset-profile_width)import(file = "./DXF/MiniChord-User_front_plate_outline.dxf",$fn=fn_body*3);
            rotate_extrude()import(file = target_curve,$fn=fn_body/2);
        }
}

difference(){
    union(){
        //Making the shell
        difference(){
            //full shape
            body(profile_added_offset,fn_base,"./DXF/MiniChord-User_edge_curve.dxf");
            //minus the top shape 
            body(profile_added_offset,fn_base,"./DXF/MiniChord-User_bottom_edge_curve.dxf");
            //emptying the interior, 2mm bottom thickness
            translate([0,0,plastic_thickness])body(-3,fn_base,"./DXF/MiniChord-User_edge_curve.dxf");
            //removing the reset zone 
            translate([0,0,-profile_height])linear_extrude(height = profile_height, center = false, convexity = 20)import (file = "./DXF/MiniChord-User_reset_zone.dxf",$fn=3*fn_base); 
            
            
            
        }
        //Adding the PCB support
        intersection(){
            difference(){
                //full shape
                body(profile_added_offset,fn_base,"./DXF/MiniChord-User_edge_curve.dxf");
                //minus the top shape
                body(profile_added_offset,fn_base,"./DXF/MiniChord-User_bottom_edge_curve.dxf");
            }
            //intersecting with the PCB support profile
            translate([0,0,-(profile_height)])linear_extrude(height =profile_height, center = false, convexity = 20)import (file = "./DXF/MiniChord-User_pcb_support.dxf",$fn=fn_base); 
        }
        //adding the reset internal cover
        difference(){
            translate([0,0,-profile_height])linear_extrude(height = profile_height-pcb_depth-plastic_thickness, center = false, convexity = 20)offset(r=1)import (file = "./DXF/MiniChord-User_reset_zone.dxf",$fn=3*fn_base); //removing the reset zone 
            translate([0,0,-profile_height])linear_extrude(height = profile_height, center = false, convexity = 20)import (file = "./DXF/MiniChord-User_reset_zone.dxf",$fn=3*fn_base); 
        }
        //adding the battery holder
         translate([0,0,-profile_height])linear_extrude(height = 3+plastic_thickness, center = false, convexity = 20)import (file = "./DXF/MiniChord-User_battery_holder.dxf",$fn=fn_base); 
        /*translate([0,0,-profile_height+plastic_thickness+3])
        roof(method="straight", convexity = 10){
             import (file = "./DXF/MiniChord-User_battery_holder.dxf",$fn=fn_base);
        }*/
        
        
    }

    //>>the PCB cut
    //Let's cut the PCB  
    translate([0,0,-plastic_thickness-pcb_depth])linear_extrude(height = pcb_depth+plastic_thickness, center = false, convexity = 20)offset(r=0.1)import (file = "./DXF/MiniChord-Edge_Cuts.dxf",$fn=3*fn_base); 
    
    //>>The bottom clearance cut
    //We need to make room 
    added_depth=pcb_bottom_clearance+pcb_depth;
    translate([0,0,-plastic_thickness-added_depth])linear_extrude(height = added_depth+plastic_thickness, center = false, convexity = 20)offset(r=0.00)import (file = "./DXF/MiniChord-User_pcb_low_clear.dxf",$fn=fn_base/2); 
    
   
   //cut for connector
    connector_center_z=-plastic_thickness-pcb_top_clearance+1.45;
    height_connector_housing=6;
    height_connector=3;

     minkowski(){
         radius_connector=0.75;
         translate([0,0,connector_center_z-height_connector/2+radius_connector])linear_extrude(height =height_connector-2*radius_connector, center = false, convexity = 20)offset(r=-radius_connector)import (file = "./DXF/MiniChord-User_pcb_usb_connector.dxf");
          sphere(r=radius_connector,$fn=fn_base);
     }
     minkowski(){
    translate([0,0,connector_center_z-height_connector_housing/2])linear_extrude(height =height_connector_housing+1, center = false, convexity = 20)offset(r=-0.5)import (file = "./DXF/MiniChord-User_pcb_usb_housing.dxf"); 
   sphere(r=0.5,$fn=fn_base);
    }
    
    //cut for headphone
    //unfortunaly I have to do it manually, centered on the middle of the end of connector
    headphone_x=101.4452;
    headphone_y=-143.9548;
    headphone_center_z=-plastic_thickness-pcb_top_clearance+2.7;
    //connector
    translate([headphone_x,headphone_y,headphone_center_z])rotate([0,0,-45]){
    translate([0,3,0])rotate([90,0,0])cylinder(d=6.4,h=200,$fn=2*fn_base);
    translate([0,3,0])rotate([90,0,0])cylinder(d=8,h=1.7,$fn=2*fn_base);
    translate([0,5,0])rotate([90,0,0])cylinder(d=8,h=3,$fn=2*fn_base);
    translate([0,2+5,0])cube([12,10,5],center=true);
    }
    
    
    //the screw hole cut, we offset the plate cutout to get them
    real_screw_d=3;
    target_screw_head=4.6;
    target_screw_body=2.9;

    additional_depth=20;
     translate([0,0,-profile_height])linear_extrude(height =profile_height, center = false, convexity = 20)offset(r=(target_screw_body-real_screw_d)/2)import(file = "./DXF/MiniChord-User_holes_housing.dxf",$fn=fn_base); 
    //let's stop 1mm before the pcb clearance
    translate([0,0,-profile_height])linear_extrude(height =profile_height-(plastic_thickness+pcb_depth), center = false, convexity = 20)offset(r=(target_screw_head-real_screw_d)/2)import(file = "./DXF/MiniChord-User_holes_housing.dxf",$fn=fn_base); 
    
   
    
}

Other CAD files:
hardware/3D/DXF/MiniChord-User_reset_zone.dxf
hardware/3D/render_v11_bottom_camera_holder.scad
hardware/3D/render_v11_top.scad
hardware/3D/DXF/MiniChord-B_Silkscreen.dxf
hardware/graphics/guide_sticker.stl

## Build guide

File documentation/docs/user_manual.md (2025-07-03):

# **Getting started**

[#1 sheet] #1 sheet

**To turn it on, simply plug the headphone jack in ①. The main led ② will shine.** If it does not turn on, then its battery is empty, charge it on any USB wallwart with a mini USB cable **③**. 

[#2 sheet] #2 sheet

**Once it is started, push one of the square buttons ④. You should hear a chord being played.** If you do not hear a sound, check that the first potentiometer is not fully turned left **⑤**. The chord will vary depending on which button you press. 

[#3 sheet] #3 sheet

**Now drag your finger across the black vertical bar ⑥. You should hear the sound of multiple notes being played sequentially, like a harp.**  If you do not hear that, check that the second potentiometer is not fully turned left **⑦**. Those notes depend on the selected chord. Push different square buttons and test the way the harp reacts.

That's it, you got started! 

**To switch the minichord off, simply remove the headphone jack**. Don't forget it plugged in or it will empty its battery!

# **Basic usage**

Chord selector buttons

## ① Chord selector buttons

The minichord has :

* **21 main chord buttons**, divided into 7 column of 3 buttons;
* **1 "sharp" button (on the top left)**.

**Each column of the main chord buttons is associated with a note of the C Major scale**. It is indicated by the letter on the first row of buttons. 

**Each row of the main chord button is associated with a chord type**:

* the first row will produce major chords;
* the second row will produce minor chords;
* the third row will produce 7th chords. 

By following the row and the column of each button, we can identify the specific chord associated. **Here is the full table of the chords available by the push of a single button**:

| **F** | **C** | **G** | **D** | **A** | **E** | **B** | |
|:-----:|:-----:|:-----:|:-----:|:-----:|:-----:|:-----:|:---:|
|F maj|C maj|G maj|D maj|A maj|E maj|B maj| **Maj**|
|F min|C min|G min|D min|A min|E min|B min| **Min**|
| F7 |C7  |G7  |D7  |A7  |E7  |B7  | **7th**|

**The "sharp" modifier button (top left) will add a semitone to each note of the chord, and can be added to any combination of the main chord buttons.**

> ⚠ In the basic usage only one chord button is pushed at a time to trigger a new chord. However, it is possible to combine buttons to construct more complex chords. This is explained in the ["Advanced usage" section]().

Harp touch zone

## ② Harp touch zone 

The harp touch zone is divided **into 12 different sections**, stacked vertically. Touching each section will trigger a note. Notes can be held by keeping in contact with the section. 

This touch zone can be "strummed" by sweeping the finger across all sections, or individual notes can be triggered. 

Preset selection buttons and indicator

## ③ Preset selection buttons and indicator

The preset selection buttons can be used to switch between presets. **The minichord has 12 internal presets** (see ["Default presets"](#default-presets)), that can be replaced by custom presets (see ["Making custom presets"](#custom-presets)). Going up after the 12th preset will circle back to the first, same as going down before the first will circle back to the 12th. 

The main led will shine with a different color for each preset to help you identify the current selected one. 

Potentiometers

## ④ Potentiometers 

Each of the three potentiometers has one main function, designated by the marking on the enclosure :

* **The first potentiometer from the top** sets up the volume of the chord section;
* **The second potentiometer from the top** sets up the volume of the harp section;
* **The third potentiometer from the top** is assigned to a different function for each preset, depending on what is usefull for it. 

> ⚠ Each of the potentiometers has a secondary function, which is explained in the ["Advanced usage" section](#advanced-usage). 

Rythm mode button and indicator

## ⑤ Rythm mode button and indicator

The rhythm mode button (on the top right) has two basic modes:

* **discrete**: the chord only stays on for as long as you keep the relevant button pushed. In that mode, the indicator led will be off.
* **continuous**: the chord will keep playing until you push a new button, and seamlessly switch to the next chord. In that mode, the indicator led will be on. 

Simply push the rhythm mode button to switch from one mode to the other. That button may also be used to switch to the arpeggiator mode with a long push, but that subject is handled in the [ "Advanced usage" section](#advanced-usage). 

Charging

## ⑥ Charging 

Charging is done through the mini USB jack available on the bottom right of the minichord. Connection to any USB outlet will do, and it will draw 500ma of current. 

**When charging, the top right led will shine red**. 

Full charge should be below 3 hours, and **the top right led will shine green once the full charge is attained**. 
Once fully charged, the minichord will play for around 7 hours. 

**When the battery is getting low, the main led will pulse**. Once the pulsing starts, the minichord can play for around 15 minutes more. You can play the minichord while plugged in. 

# **Advanced usage**

## Advanced chord selections

There are two ways to access additional chords on the minichord:

**By combining buttons within the same column**. 

combining in a column

It is possible to push more than one button within the same column to access more complicated chords. **The possible combinations are the following**:

* The button from the third row can be combined with a button from either the first or the second row of the same column to obtain a* Major 7* (①) and *Minor 7* (②) chord of the same note;
* The first and second row buttons can be combined within a column to obtain an *diminished* chord (③);
* The three buttons together can be combined to obtain an *augmented* chord (④).

>⚠ Please note that a chord change always happens when a button is pushed. Simply releasing buttons will not change the chord. This is because properly timing a release is difficult with pushbuttons and it would lead to unwanted chord change when switching from a complex chord position. For example... 

**By combining buttons across different columns**

When a chord is selected within a column (even a complex one), **it is possible to replace one of the notes with the fundamental from another column**. 

To do that simply **push any button from the column of the note you wish to borrow the fundamental from**. 

combining across columns

Usually, the replaced note is the fundamental of the chord and the substitution is known as a "slash chord", written for example Am/E for an A minor chord with E as the fundamental. However, this is not the case for all presets. That setting is indicated per preset in the [Default presets](#default-presets) section.

>⚠ Due to the way the "sharp" button works, some slash chords are impossible to do on the minichord. For example, Am/G is possible, Am#/G# is possible (by holding the "sharp" modifier button), but Am#/G is not. 

## Secondary potentiometer functions

Each of the potentiometers allows you to access a secondary function. The specific secondary function will depend on the selected preset, and is indicated per preset in the [Default presets](#default-presets) section.

**To access the secondary function, you need to hold the "sharp button" while turning the potentiometer.**

Secondary potentiometer functions

>⚠ Please note that the secondary parameter value selected will be memorized by the minichord, but only if you switch between presets (to avoid having to write to memory the selected value with every parameter change). 

## Arpeggiator

The minichord has a very basic arpeggiator function, allowing to play 16 steps pattern on the four voices of the chord section. **To activate the arpeggiator, do a long (more than 1 second) press on the "rhythm" button** (on the top right). The led will flash rythmically and the arpeggiator will start. 

Arpeggiator

**While the arpeggiator is playing, you can move from chord to chord by using the chord buttons as usual.** 

>⚠ Depending on the current playing pattern, that change may not be immediately applied and might wait until the next "strong beat". Strong beats are indicated by the rhythm led flashing a brighter than the normal flash.

**While in arpeggiator mode, the rhythm button will function as a "tap tempo"**. By tapping it rhythmically, you can change the current tempo of the arpeggiator. 

To exit the arpeggiator mode, do once again a long press on the "rhythm" button. 

# **Following chord charts**

A good way to use the minichord, especially if you want to cover some popular songs, is to use readily available chord charts.

**Chord charts are a simplified kind of tablature that only includes the lyrics and the chord of the song**. Usually, the chords are written on top of the lyrics, at the moment where they are supposed to happen in the song. 

**Chord charts are very easy to find**, usually all it takes is to google the name of the song followed by "chords".

They usually look like this:

        A              Am

        I'm not in love, so don't forget it,

        G#m7        G#7             C#m            C#m7

        It's just a silly phase I'm going through.

        A                Am

        And just because I call you up,

        G#m7           G#7     

        Don't get me wrong, 

        C#m                            C#m7

        Don't think you've got it made.
        
*Extract from the chord chart of "I'm not in love" by 10cc*

As we see, to be able to play such a chord chart, **we need to have a basic understanding of the way chords are commonly written**. Since there is no widely accepted standard, it may vary slightly between chord charts.

In the below table, we show the way chords are commonly written in a chord chart and how to play them on the minichord, with G for our fundamental:

| Full chord name | Common notations | Button selection pattern|
|---|:---:|:---:|
| Major chord | G, G major |  pattern |
| Minor chord | Gm, Gminor, Gmi, G_ | pattern |
| Dominant 7th chord | G7, G Seven, Gdom |  pattern |
| Major 7th chord | Gmaj7, GΔ, GΔ7, GM7, Gma7| pattern |
| Minor 7th chord | Gm7, G_7, Gmi7, Gmin7 | pattern |
| Diminished chord | Gdim, G° |  pattern  |
| Augmented chord | Gaug, G+ | pattern |
| Slash chord | G/F (for F substitution ) | pattern |

**Most of the time, the chords are easily playable on the minichord**. If not, it is almost always possible to find acceptable substitutions, but that might require a bit more theoretical knowledge for the player (for example to calculate which slash chord might be an acceptable ersatz for a complex chord). 

# **Custom presets**

You can easily test and save custom presets by going to the [minishop](https://minichord.com/minicontrol/minishop.html) with a a compatible web browser. We recommend using Google Chrome on desktop, because of its support of WebMidi sysex commands.

Making custom presets is a lot more involved, so it is to be reserved to more advanced users.
However, if there is an issue, you can always restore the default presets, so feel free to experiment. 

Presets are designed with an interface called [minicontrol](/minicontrol). In addition to designing your own presets, it allows you to manage the presets loaded into the 12 memory slots of your minichord, which includes loading presets shared by other users.

## minicontrol user manual 

>Please note that [minicontrol](/minicontrol) is a fully offline program, if you wish to access it when you don't have an internet connection, simply use the "save page as" option of the browser (CMD+S) to save it locally.  

**First you need to connect your minichord to minicontrol**.

To do that, first open [minicontrol](/minicontrol) in a compatible web browser. We recommend using Google Chrome on desktop, because of its support of WebMidi sysex commands.

Then connect your minichord to the computer with a USB mini cable. Please make sure that the cable used is not "charge-only" and supports data. 

Reload the webpage. You should be shown a prompt asking you to "Control and reprogram youy Midi Devices". Allow it. This is necessary to send Midi sysex commands that are used to programm the minichord. 

The minichord should then be connected. If not, a red warning should give you instructions to allow you to identify which step failed. 

**You can then circle around the presets on your minichord using the preset selection buttons on the minichord**. 

The associated internal parameters will be displayed on the screen. 

Those parameters are grouped in three categories :

* **"Global parameters"**: general parameters that impact the general functioning of the preset. It includes the reverb settings that is applied to both the chord and the harp, and the potentiometer function settings;
* **"Harp parameters"**: parameters related to the sound synthesis of the harp part of the minichord;
* **"Chord parameters"**: parameters related to the sound synthesis of the chord part of the minichord.

By hovering on each parameter name (a question mark will appear), a short description of its function will be displayed on your screen. 

You can start experimenting by modifying settings and seeing how it impacts the sound of your preset. Note that by default, changes made are not loaded into the minichord. Simply using the preset selection buttons to go one preset up then one preset down will reset the current preset. Note that the sliders can be controlled by the arrow keys to select values precisely. 

**You can then use the command buttons to modify the presets loaded on your minichord**

[minicontrol](/minicontrol) offers the following control buttons: 

  * **"Save current settings to selected bank"**: by using the dropdown to choose a bank number, you can save the current parameters to the selected bank slot. This can be used to copy presets from one bank to another;
  * **"Reset selected bank"**: by using the dropdown to choose a bank number, you can reset the parameters of the selected bank slot to factory settings
  * **"Reset all banks"**: this button simply puts the minichord to factory settings by resetting all bank slots

It also allows you to share your presets and to load presets made by other users, with two additional buttons:

* **"Share setting"**: this button will copy in your clipboard a parameter string. This parameter string fully describes the current setting playing on the minichord. 
* **"Load setting"**: this button will prompt a text entry. By pasting a parameter string it will be loaded on your minichord for you to test it. Please note that if you wish to save it into a bank slot of your minichord, you will need to use the "Save current setting to selected bank" button. 

>If you have a preset that you wish to share with all minichord users, please send the preset string with a short description and the name of your preset to [presets@minichord.com](mailto:presets@minichord.com).

## Synthesis schematic

To be able to better understand the synthesis parameters, please find below the synthesis schematics for the harp and chord section :
<div class="synthesis_container">
  <pre><code>

 Harp section                         ┌ ─ ─ ─ ─ ─ ─ ─ ─ ─ ─ ─ ─ ─ ─ ─ ─ ─ ─ ─ ─ ─ ─ ─ ─ ─ ─ ─ ─
                                     ┌────────────────────────────────────────────────────────┐│ x12
                                    ┌┴───────────────────────────────────────────────────────┐│
┌─────────┐                         │┌────────────────┐                                      │││
│DC signal├────────────────────────▶││filter enveloppe│──────────┐          ┌───────────────┐││
└─────────┘                         │└────────────────┘          └─────────▶│low-pass filter│││├───┐
┌───────────┐   ┌────────────────┐  │┌─────────────────────┐  ┌────────┐ ┌─▶│               │││    │
│vibrato OSC├──▶│vibrato envelope├┬▶││modulated string OSC ├─▶│envelope├─┘  └───────────────┘││┘   │
└───────────┘   └────────────────┘│ │└─────────────────────┘  └────────┘                     ├┘    │
                                  │ └────────────────────────────────────────────────────────┘     │
┌───────────┐   ┌────────────────┐│                                                                │
│  bend DC  ├──▶│  bend envelope ├┘                                                                │ 
└───────────┘   └────────────────┘                                                                 │                    
                                                                                                   │
┌──────────────────────────────────────────────────────────────────────────────────────────────────┘
│  ┌──────────┐  ┌─────────────┐  ┌─────────────┐  ┌─────┐  ┌────────────┐      ┌──────────┐
├─▶│waveshaper├─▶│ waveshaper  ├┬▶│  delay mix  ├─▶│delay├─▶│filter delay├─┬───▶│effect mix├───────┐
│  └──────────┘  │     mix     ││ │             │  └─────┘  └────────────┘ │ ┌─▶│          │       │
└───────────────▶│             ││ │             │                          │ │  └──────────┘       │
                 └─────────────┘│ └─────────────┘                          │ │                     │
                                │        ▲                                 │ │                     │
                                │        └─────────────────────────────────┘ │                     │
                                └────────────────────────────────────────────┘                     │
┌──────────────────────────────────────────────────────────────────────────────────────────────────┘
│              ┌──────────┐              ┌─────────────┐  ┌──────┐  ┌──────────┐
└─────────────▶│multiplier├─────────────▶│output filter├┬▶│reverb├─▶│reverb mix├─▶ output
┌───────────┐  │          │┌──────────┐  │             ││ └──────┘  │          │
│tremolo OSC├─▶│          ││filter OSC├─▶│             │└──────────▶│          │
└───────────┘  └──────────┘└──────────┘  └─────────────┘            └──────────┘

 Chord section     ┌──────────────────────────────────────────────────────────────────────┐
                  ┌┴─────────────────────────────────────────────────────────────────────┐│ x4
                 ┌┴─────────────────────────────────────────────────────────────────────┐││
                ┌┴─────────────────────────────────────────────────────────────────────┐│││
┌───────────┐   │┌────────────────┐  ┌───────────────┐  ┌─────┐  ┌──────┐  ┌──────────┐││││
│vibrato OSC├─▶ ││vibrato envelope├┬▶│modulated OSC 1├─▶│ mix ├─▶│filter├─▶│multiplier│││││
└───────────┘   │└────────────────┘│ ├───────────────┤  │     │  └──────┘  └──────────┘││││
┌───────────┐   │┌────────────────┐├▶│modulated OSC 2├─▶│     │     ▲           ▲      ││││
│  bend DC  ├─▶ ││vibrato envelope├│ ├───────────────┤  │     │     │           │      ││││────────┐
└───────────┘   │└────────────────┘└▶│modulated OSC 3├─▶│     │     │           │      ││││        │
                │                    └─────────┬─────┤  │     │     │           │      ││││        │
                │                              │noise├─▶│     │     │           │      ││││        │
┌──────────┐    │┌───────────────┐             └─────┘  └─────┘     │           │      ││││        │
│filter OSC├──▶ ││filter envelope├──────────────────────────────────┘           │      ││││        │
└──────────┘    │└───────────────┘                                              │      ││││        │
┌───────────┐   │┌────────────────┐                                             │      ││├┘        │
│tremolo OSC├─▶ ││tremolo envelope├─────────────────────────────────────────────┘      │├┘         │
└───────────┘   │└────────────────┘                                                    ├┘          │
                └──────────────────────────────────────────────────────────────────────┘           │
                                                                                                   │
┌──────────────────────────────────────────────────────────────────────────────────────────────────┘
│  ┌──────────┐  ┌─────────────┐  ┌─────────────┐  ┌─────┐  ┌────────────┐      ┌──────────┐
├─▶│waveshaper├─▶│ waveshaper  ├┬▶│  delay mix  ├─▶│delay├─▶│filter delay├─┬───▶│effect mix├───────┐
│  └──────────┘  │     mix     ││ │             │  └─────┘  └────────────┘ │ ┌─▶│          │       │
└───────────────▶│             ││ │             │                          │ │  └──────────┘       │
                 └─────────────┘│ └─────────────┘                          │ │                     │
                                │        ▲                                 │ │                     │
                                │        └─────────────────────────────────┘ │                     │
                                └────────────────────────────────────────────┘                     │
┌──────────────────────────────────────────────────────────────────────────────────────────────────┘
│  ┌─────────────┐  ┌──────┐  ┌──────────┐
└─▶│output filter├┬▶│reverb├─▶│reverb mix├─▶ output
   │             ││ └──────┘  │          │
   │             │└──────────▶│          │
   └─────────────┘            └──────────┘
    </code></pre>
</div>

# **MIDI support**

When plugged in to a computer through USB, the minichord will appear as a MIDI instrument exposing two separate MIDI port. The first port carries the MIDI signal from the chord section, and the second port from the harp section. The minichord has to be turned on to appear, so make sure that an audio output cable is plugged in to the minichord. 

For example, using the "Audio MIDI Setup" utility of macOS we can look at the characteristics of the minichord

Midi screen

The potentiometers control the velocity of the notes of each port. All notes are sent to the channel 1 of each port. Each port can be independently assigned to virtual instruments by most music softwares. For example, using Surge XT, using the option screen allows to select which midi input to active.

Surge XT screen

The minichord stays usable with softwate that does not distinguish between ports (such as GarageBand), but all of the notes will be attributed to a single instrument. 

# Updating the firmware

The process to update the minichord firmware is quite simple. 

First you need to install the application that will allow to upload the firmware. It is provided by PJRC and precise instruction for it are available [on their website](https://www.pjrc.com/teensy/loader.html). It supports macOS, Linux and Windows. 

To upload the firmware, please use the following steps:

* Plug the battery into the minichord;
* Plug in the micro USB cable between the minichord and your computer;
* Plug the headphone into the minichord 
* Open the Teensy Loader; 
* Download the hex file of the latest firmware from the [Source section](/source);
* Drop the hex file on the Teensy loader;

Once all those steps are done, use a thin pin (for example a hair pin) to push into the hole at the back of the minichord

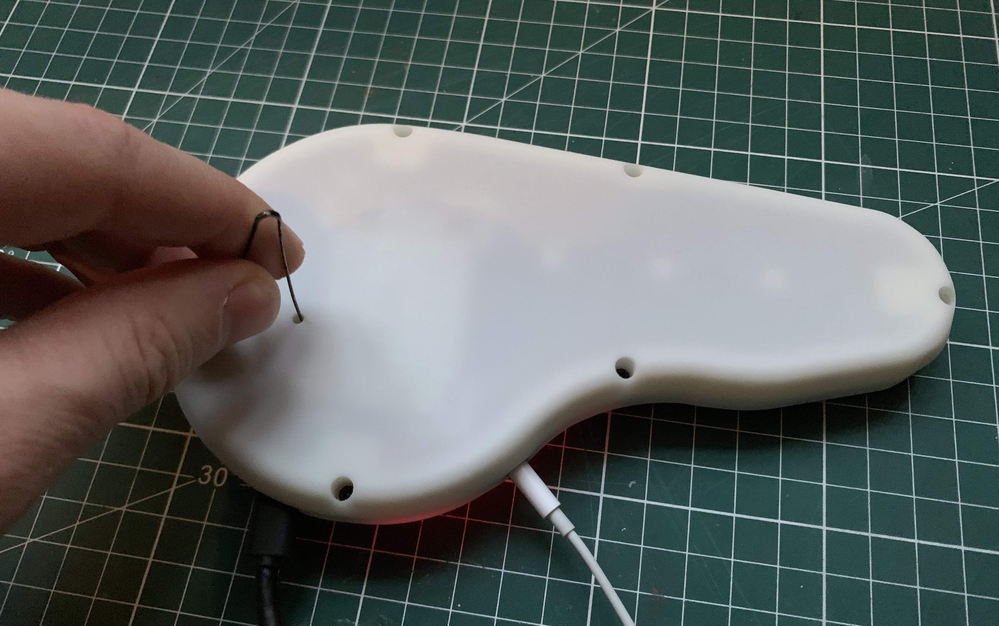
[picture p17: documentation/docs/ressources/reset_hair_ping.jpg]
resetting the Teensy


If you carefully followed those steps, the Teensy Loader will indicate "Download Complete" then "Reboot OK". The main colour led of the PCB should light up. 

After an update, it might be necessary to use [minicontrol](/minicontrol) to wipe all presets back for factory using the "reset all banks" option, as changes might render previous presets incompatible (or at least weird-sounding).

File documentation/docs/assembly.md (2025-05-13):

> **Note: While the minichord kits are not yet for sale, they might be soon. To be informed about the project and the release date of those kits, please subscribe to [the newsletter](https://buttondown.com/BenjaminPoilve).**

# **Assembly notes**

Please note that depending on the kit version, you may not have to follow all the steps:

* If you are building a minichord from scratch, start at [PCB Manufacturing](#pcb-manufacturing)
* If you have a minichord kit start at [Enclosure Manufacturing](#enclosure-manufacturing)

In any case, bill of material (BOM) and necessary tools are listed at the beginning of each section.

# **PCB Manufacturing**

Manufacturing files for the PCB are available in the [Source section](/source) in Gerber format. 

the two minichord PCB

A minichord is composed of two PCB:

* The main PCB that is a four layer 1.6mm board;
* The touch zone PCB that is a two layer 1.6mm board (please remember that this PCB will be visible, so choose colour accordingly and remove any marking that the fab house would like to add). 

Any good fab house should accept those files for manufacture.

# **SMD Soldering**

The main PCB requires some SMD components. The list if available [here](https://github.com/BenjaminPoilve/minichord/blob/main/hardware/BOM/electronics_BOM.csv). If you are experimented with SDM soldering it is possible to do that step yourself. However it requires quite advanced capabilities to properly solder the IC packages used. 

For the placement of the component, please refer to [this document](./ressources/smd_assembly/g66188.png).

For the manufacturer reference of the different components, please refer to [this document](https://github.com/BenjaminPoilve/MiniChord/blob/main/hardware/BOM/electronics_BOM.csv).

Once all the component are soldered, your PCB should look like this:

After SMD assembly after SMD assembly

# **Through-hole soldering**

<details>
    <summary> <b>BOM</b> </summary>
<table class="table table-striped table-hover">
<thead>
<tr>
<th><strong>ID</strong></th>
<th><strong>Part</strong></th>
<th><strong>Link</strong></th>
<th><strong>Quantity</strong></th>
</tr>
</thead>
<tbody>
<tr>
<td><strong>D1</strong></td>
<td>Red LED</td>
<td><a href="https://www.mouser.fr/ProductDetail/604-WP169XID">Mouser</a></td>
<td>1</td>
</tr>
<tr>
<td><strong>D2</strong></td>
<td>5mm RKGB LED</td>
<td>-</td>
<td>1</td>
</tr>
<tr>
<td><strong>J2</strong></td>
<td>Switched Audio Jack&nbsp;</td>
<td><a href="https://www.mouser.fr/ProductDetail/490-SJ-3566AN">Mouser</a></td>
<td>1</td>
</tr>
<tr>
<td><strong>J3</strong></td>
<td>JST PH 2mm 2pin male angled</td>
<td>-</td>
<td>1</td>
</tr>
<tr>
<td><strong>N/A</strong></td>
<td>503450 1000mAh battery</td>
<td>-</td>
<td>1</td>
</tr>
<tr>
<td><strong>&gt;&nbsp; RV1-RV3</strong></td>
<td>Potentiometer</td>
<td><a href="https://www.mouser.fr/ProductDetail/317-2090F-100K">Mouser</a></td>
<td>3</td>
</tr>
<tr>
<td><strong>&gt;&nbsp; SW22, SW24, SW25, SW26</strong></td>
<td>Tactile switch 6x6mm</td>
<td><a href="https://www.mouser.fr/ProductDetail/653-B3F-1050">Mouser</a></td>
<td>4</td>
</tr>
<tr>
<td><strong>&gt;&nbsp; SW1-SW21</strong></td>
<td>Tactile switch 12x12mm</td>
<td><a href="https://www.mouser.fr/ProductDetail/653-B3F-4050">Mouser</a></td>
<td>21</td>
</tr>
<tr>
<td><strong>&gt;&nbsp; J1, J4</strong></td>
<td>Touch header female</td>
<td><a href="https://www.mouser.fr/ProductDetail/855-M20-7810345R">Mouser</a></td>
<td>2</td>
</tr>
<tr>
<td><strong>N/A</strong></td>
<td>Touch header male</td>
<td><a href="https://www.mouser.fr/ProductDetail/855-M20-8760346">Mouser</a></td>
<td>2</td>
</tr>
<tr>
<td><strong>U1</strong></td>
<td>Teensy 4.0</td>
<td>PJRC</td>
<td>1</td>
</tr>
<tr>
<td><strong>N/A</strong></td>
<td>Teensy headers</td>
<td><a href="https://www.mouser.fr/ProductDetail/200-TSW13220TS">Mouser</a></td>
<td>1</td>
</tr>
</tbody>
</table>

<p>To facilitate ordering from Mouser, here is a <a href="https://www.mouser.fr/api/CrossDomain/GetContext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">prefilled basket</a>. </p>
</details>

<details>
    <summary> <b>Tools</b> </summary>
    <ul>
<br>
<li>Soldering iron and solder wire; </li>
<li>X-acto knife (or another precise cutter);</li>
<li>Diagonal cutting pliers (the Knipex "Super Knips" are worth the price);</li>
<li>[Optional] Multimeter.</li>
</ul>
</details>
<hr>

Before starting the soldering, it might be useful to identify the position of each component and do a dry run assembly. This will ensure you properly identify the position of each part and, in consequence, that you indeed have all the components of the BOM. 

## Teensy preparation 

Before soldering, some small modifications need to be made to the Teensy 4.0 Board. 

**The onboard led needs to be disabled**. This step is purely aesthetic so if you don't feel confortable doing that modification it is ok (it will simply give your minichord a soft orange glow). 

The led is next to the pin 13 of the Teensy. To identify it, simply plug your teensy using a micro USB cable. The led will blink.

identifying the led

There is a trace on the top side between the led and the reset pushbutton. Cut that trace using the X-acto (the specific position is in red in the image below). 

cutting the led

Plug the Teensy again, and check that the led is not blinking anymore. To make sure that you did not damage the Teensy, you can simply use the Teensyduino program to upload any sketch and check that it is still working normally (while the led is not glowing). 

**Then we need to cut the USB power**. This step is not optional as it allows battery to function as expected. USB power will then be routed to the battery for charging and the Teensy will only be powered when an audio jack is inserted. 

There is pads on the belly of the Teensy specifically for that reason. It is situated next to the 5V pin. With the X-acto, cut the trace between the two exposed pads. 

cutting the VUSB

Once it is done, it's a good idea to check with a multimeter that there is indeed no contact between the two pads. 

checking the cut

## Pushbuttons soldering

### 12x12mm pushbuttons

Let's start with the 12x12mm pushbuttons. The first step is to insert them all (21) on the PCB. It is a close fit, so to make it easier start with the middle line of buttons. 

putting the buttons in place

They need to be pushed firmly onto the PCB to properly latch. Make sure that they are all in place and seating flat before starting the soldering. 

soldering the buttons

### 6x6mm pushbuttons

The process is very similar to the 12x12mm button. First insert all the four pushbuttons, making sure they are fully seated before soldering.

Once done your PCB should look like this:

after soldering all the buttons

## Audio jack soldering

As before, make sure the jack is fully seated before soldering. 

soldering the jack

> Note: in PCB v0.3 and before, it is necessary to:

> * cut the top left contact of the Audio jack before soldering (when looking from the top of the PCB, with the jack entry at the bottom);
> * add  a 10k pulldown resistor between the enable and ground pin of the jack (both at the center of it).

## Led soldering 

Two leds need to be soldered. 

**First the RGB led**. The provided led is a RKGB led. Those letters indicate the order of the pins, with R, G and B for the individual colours and K for the common cathode. The K pin is the longest and the position of each pin is indicated on the PCB itself. 

The RGB led needs to be fully seated in place before soldering. 

soldering the RGB led

Once soldered, cut the lead flush with the diagonal cutter. 

**The next one is the red led**. The longest pin is the +, and the position of each pin is indicated on the PCB itself. 

This led should not be fully seated. the top of the led should be about the level of the top of the pushbutton next to it.

soldering the red led

Once soldered, cut the leads flush with the diagonal cutter. 

## Header soldering

Now we need to solder the female header that will allow the touch PCB to connect. 

Those headers are really SMD components but they are really easy to solder. Just put them in place, making sure they are flush (they should hold in place) and solder each pin. 

soldering the headers

## Teensy soldering

First prepare the headers using the X-acto knife. You will need:

* Two 14-long header strip for each side of a Teensy;
* A lone header for the out-of-row contact for the VUSB pin. If you are unsure which pin it refers to, take a moment to look at the [Teensy pinout card](https://www.pjrc.com/teensy/card10b_rev2_web.pdf) to identify it and locate its position on the PCB. **Failure to place correctly that header will keep the battery from charging.**

Now you can place the headers on the board, with the short length on the Teensy's side. **Position the Teensy, belly up**, and make sure it is correctly seated. You can then solder the two end of each header line to "tack" the header in place. 

tacking the Teensy

Check that the Teensy is well seated, then do the same on the PCB's side. After a final check that the Teensy is well seated, you can then go over all the contact, both on the Teensy and on the PCB's side and solder them. **Don't forget to solder the VUSB pin**. 

soldering the Teensy

## Potentiometers

First place the three potentiometer. 

installing the potentiometers

Note that a low-profile trace is used, which means that the potentiometer sit deeper than they usually would. Make sure that they are fully seated. 

well seated potentiometer

They will hold in place while you solder them. 

## Battery connector

This component is on the backside of the PCB. The silkscreen show the correct position for the connector, so place it accordingly.

**If the connector is installed backward and the battery is connected that way, it will destroy the device**. You need to make sure that when the battery will be connected, the polarity will be respected. 

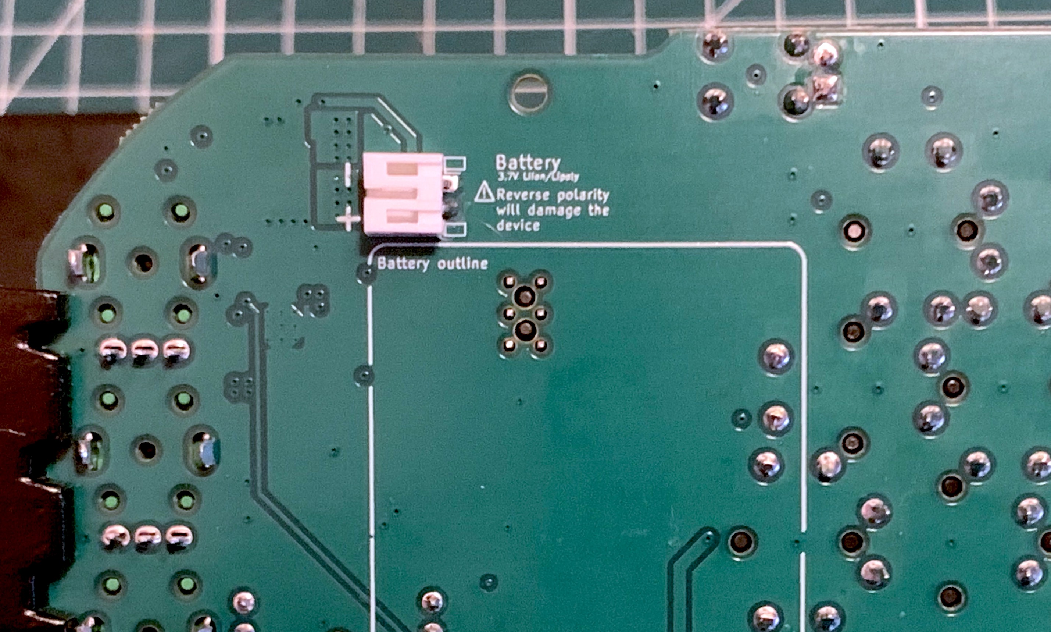
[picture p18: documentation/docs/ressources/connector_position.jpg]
positionning the connector


> Note: If you purchased the battery yourself, you need to make sure the connector attached to it is not reversed, as it sometimes happen. In that case choose the orientation of the connector to solder to make sure that the red wire of the battery indeed is connected to the positive side (following the silkscreen marking). 

## Cutting excess leads in the battery zone 

On the backside on the PCB note a white silkscreen rectangle showing the position of the battery inside the enclosure. 

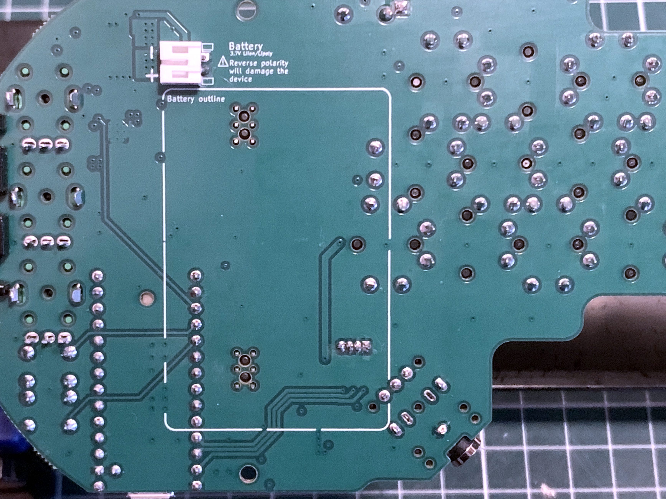
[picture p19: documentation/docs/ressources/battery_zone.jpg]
battery zone


Using diagonal cutters, make sure to cut any leads whithin that white rectangle that is protruding more than 1mm. This is to avoid having those leads touch the battery pouch and potentially damage them 

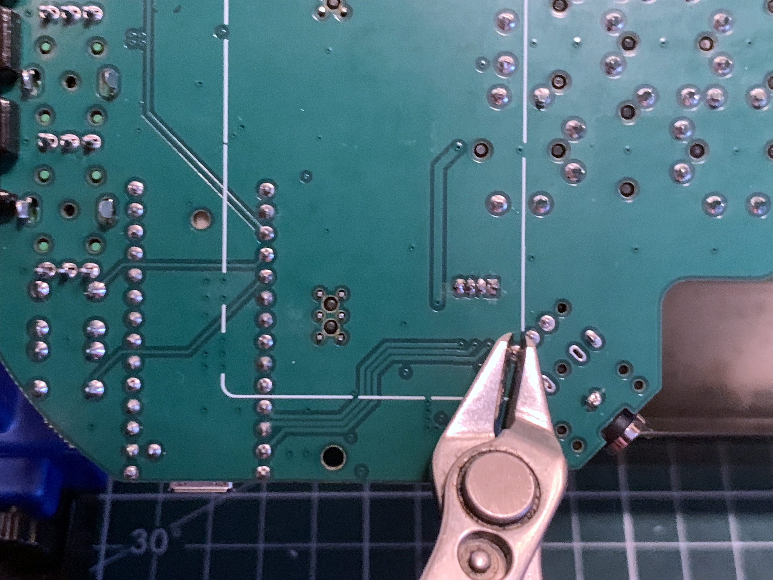
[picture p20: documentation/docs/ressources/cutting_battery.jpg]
cutting excess


## Soldering of touch zone PCB

The last bit of soldering needed is the headers on the touch zone PCB. Once again, those are technically SMD components, but easy enough to solder. Just make sure they are well aligned. 

touch zone pcb soldering

# **Firmware uploading**

<details>
    <summary> <b>BOM</b> </summary>
    <ul>
<br>
<li>Fully assembled minichord PCB; </li>
<li>503450 1000mAh battery;</li>
</ul>
</details>
<details>
    <summary> <b>Tools</b> </summary>
    <ul>
<br>
<li>Micro USB cable (make sure it supports data transfert); </li>
<li>Computer (whether Windows, OSX or Linux);</li>
<li>Headphones;</li>
</ul>
</details>
<hr>

## Testing the board

First it is necessary to make sure the board is properly functioning. 

Without plugging the battery, plug in the micro USB. The power status led should light up (green or red depending on the specific led model). 

first led test.

If it does not light up, one the most likely reason is that you forgot to solder the VUSB header. Go back to the [Through-hole soldering](#through-hole_soldering) section and read carefully the part about the Teensy soldering. 

Then plug in the battery. **Make sure that the polarity is respected** (it should be the case if you followed previous instructions). This time the led will be red, indicating that the battery is charging. 

second led test.

## Installing the Teensy Loader Application

Next you need to install the application that will allow to upload the firmware. It is provided by PJRC and precise instruction for it are available [on their website](https://www.pjrc.com/teensy/loader.html).

Please note that if you have TeensyDuino installed, the Teensy Loader is included with it. 

## Uploading the firmware

To upload the firmware, please use the following steps:

* Plug the battery into the minichord;
* Plug in the micro USB cable between the minichord and your computer;
* Plug the headphone into the minichord 
* Open the Teensy Loader; 
* Download the hex file of the firmware from the [Source section](/source);
* Drop the hex file on the Teensy loader;

Once all those steps are done, use a header to push on the reset button of the Teensy through the PCB hole. 

resetting the Teensy

If you carefully followed those steps, the Teensy Loader will indicate "Download Complete" then "Reboot OK". The main colour led of the PCB should light up. 

the board if functionning

You can test it by putting the headphones to your hears and push one of the 12x12mm buttons. If you don't hear anything, check that the potentiometers are not turned fully counter-clockwise.

# **Enclosure manufacturing**

The enclosure is composed of two part, the top and the bottom shell. The STL file for those parts is available in the [Source section](/source).

> Note: This section show an earlier version of the enclosure

## Printing the parts

Depending on what equipment you have available, **you can choose different alternatives for manufacturing**. 

### FDM printing

If you have a FDM printer, you can use it to make the top and bottom shell. They fit comfortably on a 18x18cm bed. Make sure that you flip the objects to have the flat surface on the bed, no support is required for printing. 

Indicatively, on my Prusa Mini+:

* the top shell takes 2 hours to print on a 0.15mm layer height;
* the bottom shell takes 2 hours and 15 minutes to print on a 0.15mm layer height.

The result is satisfactory, though not great. 

FMD shells

#### SLA resin printing 

For better quality part, SLA resin printing is an economical alternative. Though the equipment is costly, multiple vendors offer affordable online printing services. 

It should cost less than 5€ per part for basic resin choices, for very qualitative parts. Currently 9600 resin is my favorite for a low cost and good quality. 

Resin shells

It also possible (for a cost around 1.5x to 2x) to print those part with a transparent resin. 

Transparent shells

Whether normal or transparent resin, it is possible to use GTC liquid dyes to dye the part, for a very good final result.

coloured shell

# **Final assembly**

<details>
    <summary> <b>BOM</b> </summary>
    <ul>
<br>
<li>Fully assembled minichord PCB; </li>
<li>Fully assembled touch zone PCB; </li>
<li>Keycap set; </li>
<li>503450 1000mAh battery;</li>
<li>Top and bottom shells;</li>
<li>6x M2.3x8 self-tapping screws;</li>
<li>3x M2.3x6 self-tapping screws;</li>
<li>Double-sided tape.</li>
</ul>
</details>
<details>
    <summary> <b>Tools</b> </summary>
    <ul>
<br>
<li>X-acto knife (or another precise cutter); </li>
<li>Phillips electronics screwdriver.</li>
</ul>
</details>
<hr>

## Marking the keycap 

The first row of keycaps need to be marked with the chord letters. If you have a CNC router, then it is possible to engrave the keycap with a 45° V cutter, using a V-carve mode. 

For Omron Keycap, I've found the following setting to be satisfying:

* 300 mm/min feed rate; 
* 150 mm/min plunge rate; 
* 10 000 rpm.

CNC engraving

Once the keycap are engraved, the engraving is filled using Markal "Lacquer fill-in" paint stick. The following steps are recommanded: 

* "sharpen" the paintstick with an X-acto to have a pointy end;
* overfill the engraving with color;
* wait for at last 15 hours for the paint to start solidifying;
* buff the surplus color out. Place a tissue paper flat on a table, and rub the keycap on it while maintaining it very flat to remove the color outside of the groove. You may need to do it in several passes, changing the tissue paper in between. To properly remove all remaining color, a few drops of isopropyl might help. 

keycaps

Alternatively, if you don't have a CNC router, you can look into UV DTF transfers. It is a cheap method to allow color tranfers that can work for details up to 0.5mm. 

Once you engraved keycap are finished, you can install all the buttons on the main PCB. 

The engraved buttons go on the first line, and the order is F,C,G,D,A,E,B from left to right 

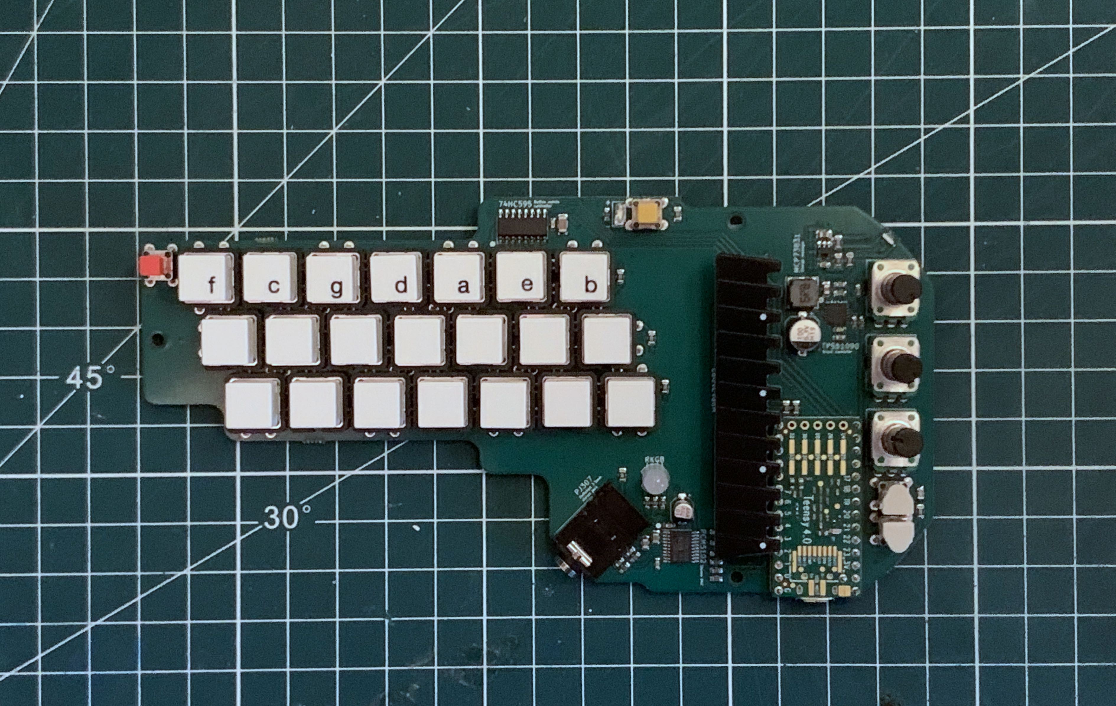
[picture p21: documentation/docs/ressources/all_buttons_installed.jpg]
all buttons installed


## Assembling the enclosure

Now the easiest step ! 

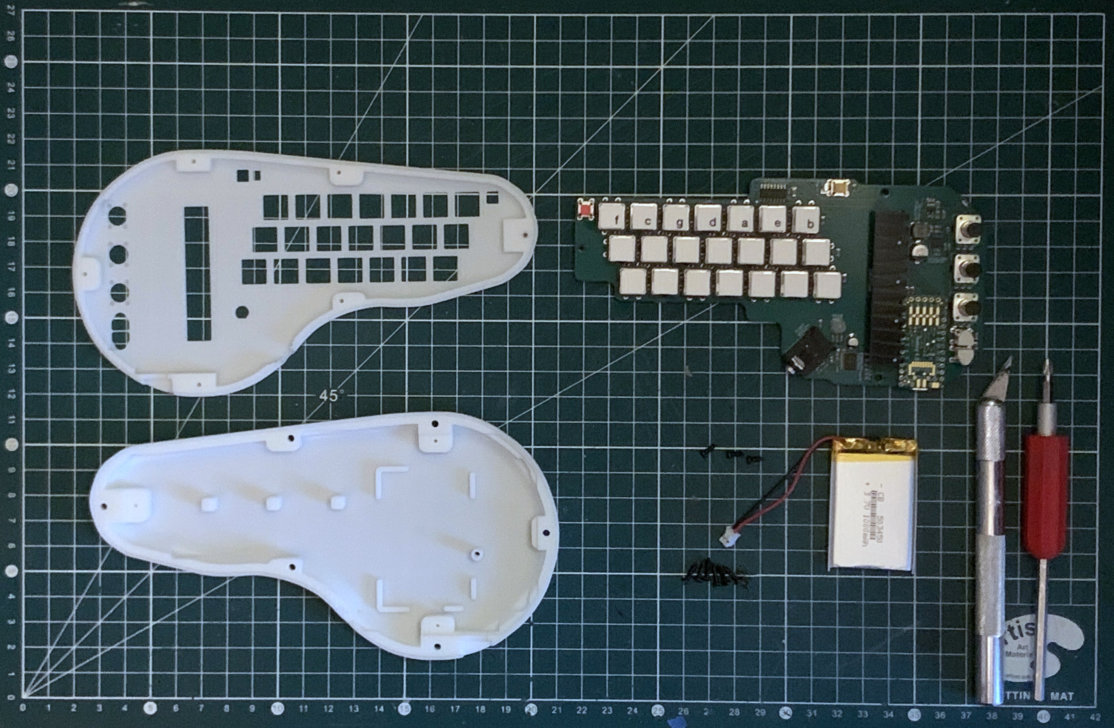
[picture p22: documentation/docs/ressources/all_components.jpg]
all components


To avoid any screw breakage, please follow closely the following instruction:

* Use a adequately sized screwdriver. In particular, if you screwdriver slips, it might strip the screw and make the assembly impossible;
* Pre-tap the holes on the top shell. To do that, use one of the three _small_ screw. Simply fully screw it into each one of the hole, then take it out. Repeat for each of the six holes. Do not use one of the long screw for that step.

Now to the assembly itself :

First add a strip of double sided tape on the battery to install the battery in the dedicated space on the bottom shell. 
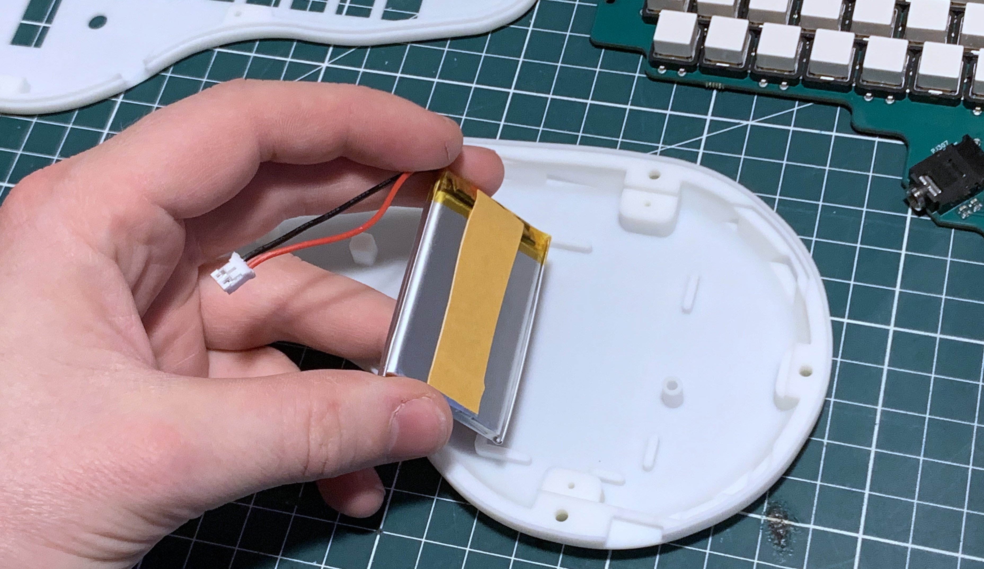
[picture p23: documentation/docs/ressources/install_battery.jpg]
install battery installing the battery


Then connect the battery to the PCB. Add a material on top of the battery to protect againt any contact (bubble wrap, foam board, etc.).
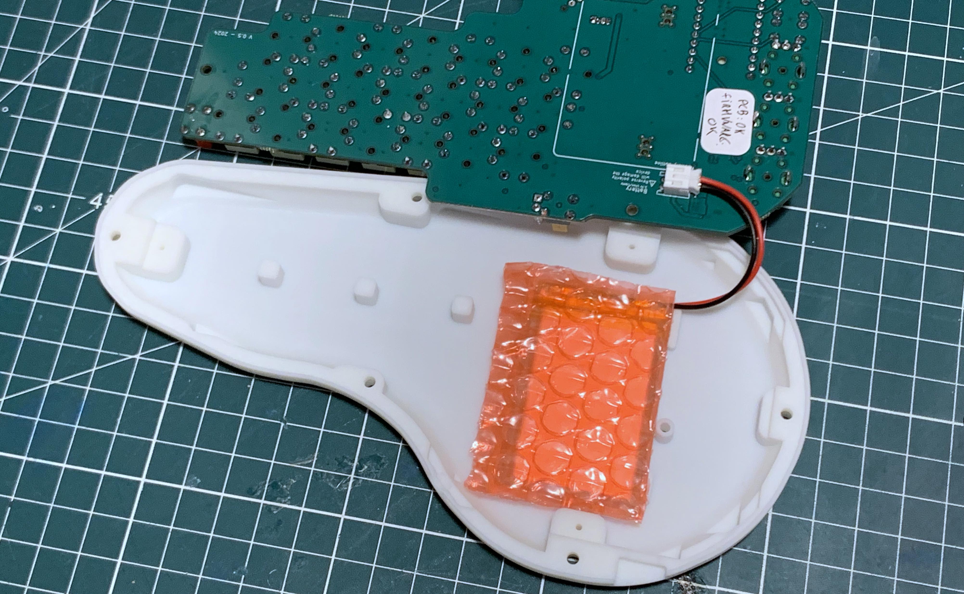
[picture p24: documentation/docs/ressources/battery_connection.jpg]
connecting the battery


You can then put the PCB in place (it should snap fit into place) and secure it with the three small screws. Be sure to not overtighten the screws: once you feel a resistance, it is enough. 

bottom installed

No install the top shell. Make sure that all keycap are well-aligned with their respective holes. Once it is the case, it should be easy to push the top shell in place. 

Secure the top shell with the six long screws. Be sure to not overtighten the screws: once you feel a resistance, it is enough. 

top installed

The last step is to install the touch zone PCB. Simply be carefull that the header are in their right place, and push it until it makes contact with the shell. 

finished

That's it, your minichord is done! No to use it, please refer to the ["manual" section](/user_manual)

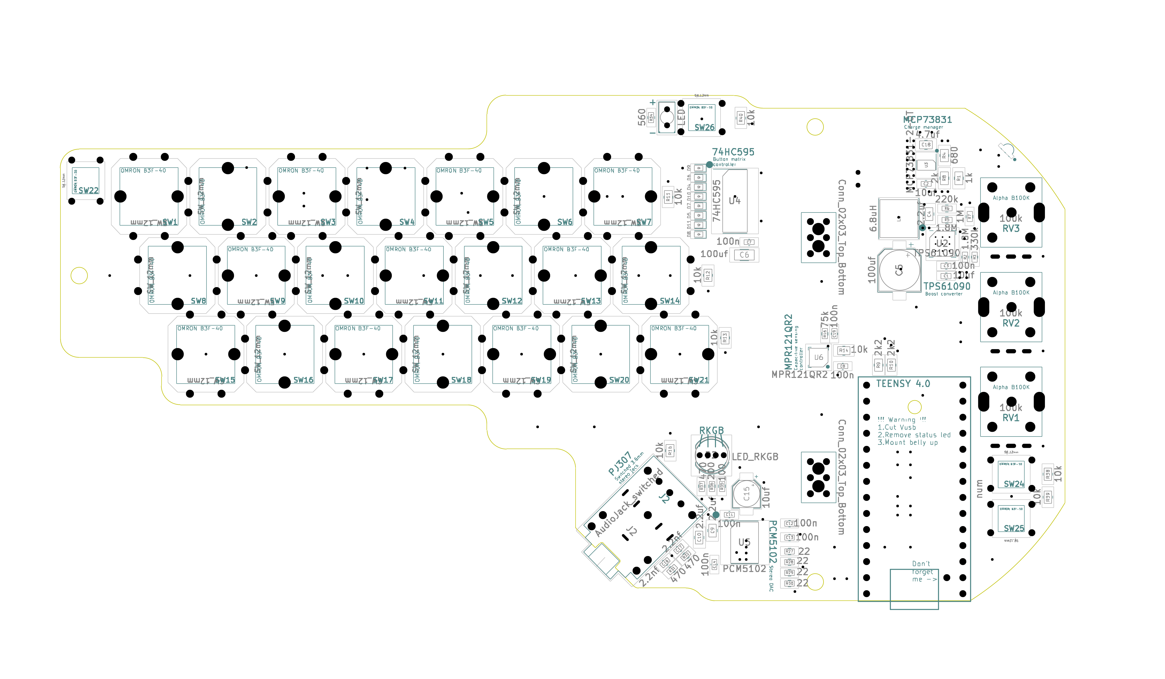
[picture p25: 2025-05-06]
documentation/docs/ressources/smd_assembly/g66188.png

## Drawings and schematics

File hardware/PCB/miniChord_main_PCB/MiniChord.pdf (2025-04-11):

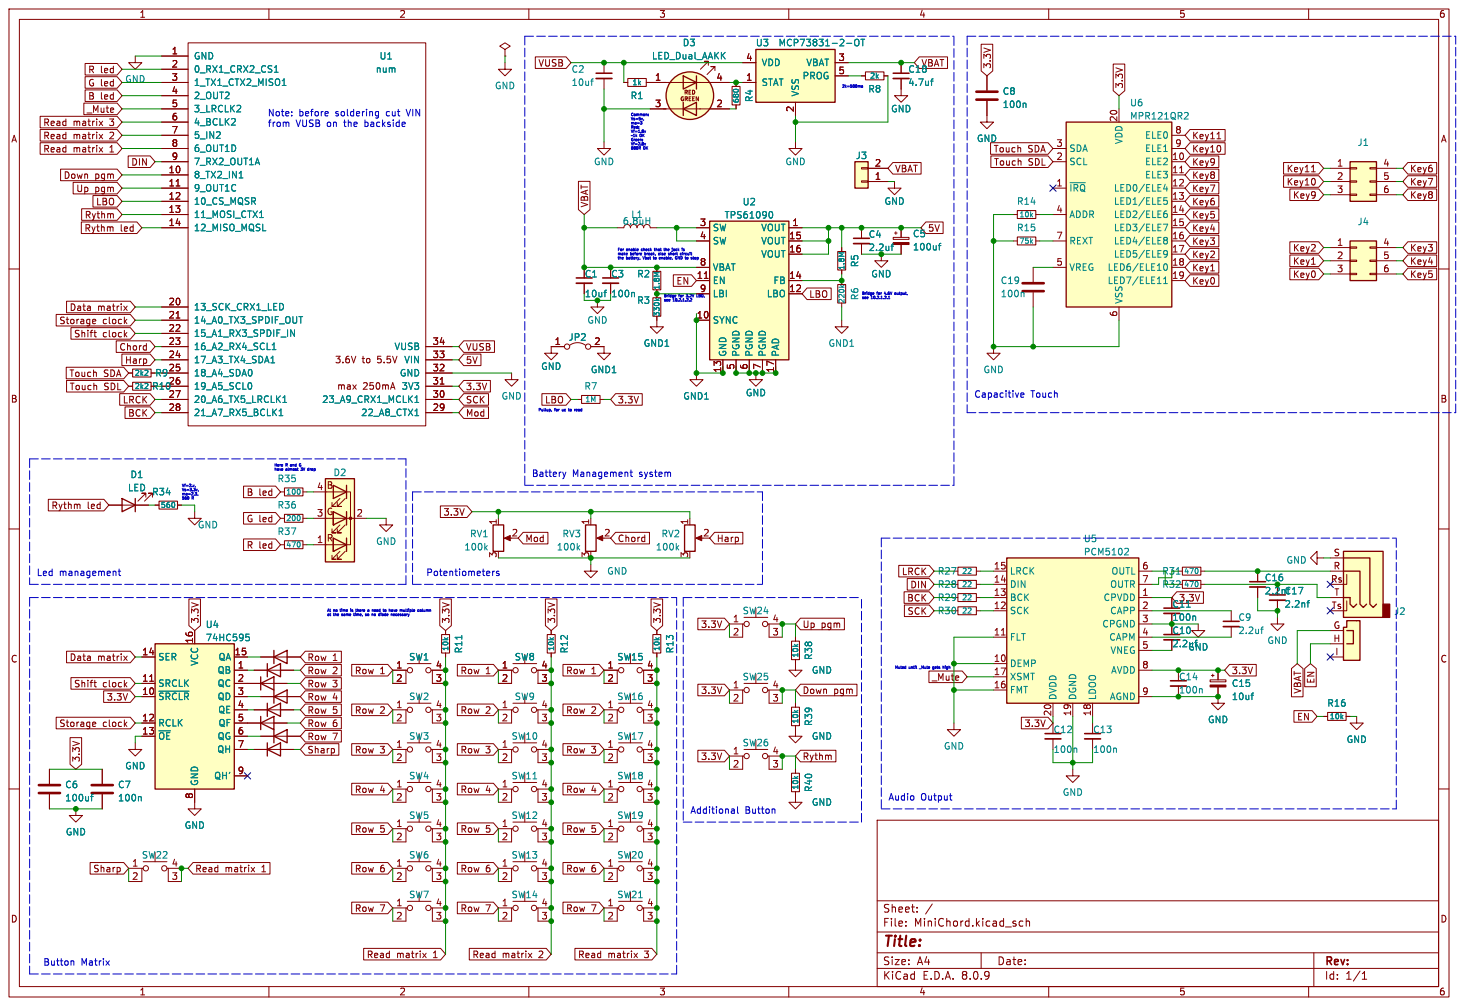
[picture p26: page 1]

2 VBAT 3 VDD 4 PROG 5 U3 MCP73831-2-OT

from VUSB on the backside

Id: 1/1 Title: File: MiniChord.kicad_sch Sheet: /

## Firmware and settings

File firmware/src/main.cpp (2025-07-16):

#include "audio_definition.h"
#include "def.h"
#include <AT42QT2120.h>
#include <Arduino.h>
#include <Audio.h>
#include <LittleFS.h>
#include <SPI.h>
#include <Wire.h>
#include <button_matrix.h>
#include <debouncer.h>
#include <harp.h>
#include <potentiometer.h>

//>>SOFWTARE VERSION 
int version_ID=0006; //to be read 00.03, stored at adress 7 in memory
//>>BUTTON ARRAYS<<
debouncer harp_array[12];
debouncer chord_matrix_array[22];

//>>HARDWARE SETUP<<
harp harp_sensor;
button_matrix chord_matrix(SHIFT_DATA_PIN, SHIFT_STORAGE_CLOCK_PIN, SHIFT_CLOCK_PIN, READ_MATRIX_1_PIN, READ_MATRIX_2_PIN, READ_MATRIX_3_PIN);
debouncer hold_button;
debouncer up_button;
debouncer down_button;
debouncer LBO_flag;
bool flag_save_needed=false; //to know if we need to save the preset
potentiometer chord_pot(POT_CHORD_PIN);
potentiometer harp_pot(POT_HARP_PIN);
potentiometer mod_pot(POT_MOD_PIN);
LittleFS_Program myfs; // to save the settings
float color_led_blink_val = 1.0;
bool led_blinking_flag = false;
float led_attenuation = 0.0; 
//>>CHORD DEFINITION<<
//for each chord, we first have the 4 notes of the chord, then decoration that might be used in specific modes
uint8_t major[7] = {0, 4, 7, 12, 2, 5, 9};  // After the four notes of the chord (fundamental, third, fifth of seven, and octave of fifth, the next notes are the second fourth and sixth)
uint8_t minor[7] = {0, 3, 7, 12, 1, 5, 8};
uint8_t maj_sixth[7] = {0, 4, 7, 9, 2, 5, 12};
uint8_t min_sixth[7] = {0, 3, 7, 9, 1, 5, 12};
uint8_t seventh[7] = {0, 4, 10, 7, 2, 5, 9};
uint8_t maj_seventh[7] = {0, 4, 11, 7, 2, 5, 9};
uint8_t min_seventh[7] = {0, 3, 10, 7, 1, 5, 8};
uint8_t aug[7] = {0, 4, 8, 12, 2, 5, 9};
uint8_t dim[7] = {0, 3, 6, 12, 2, 5, 9};
uint8_t full_dim[7] = {0, 3, 6, 9, 2, 5, 12};
uint8_t key_signature_selection = 0; // 0=C, 1=G, 2=D, 3=A, 4=E, 5=B, 6=F, 7=Bb, 8=Eb, 9=Ab, 10=Db, 11=Gb
enum KeySig { // Enums for KeySigs
  KEY_SIG_C, KEY_SIG_G, KEY_SIG_D, KEY_SIG_A, KEY_SIG_E, KEY_SIG_B,
  KEY_SIG_F, KEY_SIG_Bb, KEY_SIG_Eb, KEY_SIG_Ab, KEY_SIG_Db, KEY_SIG_Gb
};
enum Button { // Button enum in hardware order: B, E, A, D, G, C, F
  BTN_B, BTN_E, BTN_A, BTN_D, BTN_G, BTN_C, BTN_F
};
enum FrameShift { //Enums for chord frame shifts
  FRAMESHIFT_0, FRAMESHIFT_1,FRAMESHIFT_2,FRAMESHIFT_3,FRAMESHIFT_4,FRAMESHIFT_5,FRAMESHIFT_6
};
const int8_t base_notes[7] = {11, 4, 9, 2, 7, 0, 5}; // Base note offsets for buttons in key of C (relative to C4 = MIDI 60), in hardware order B, E, A, D, G, C, F
const int8_t key_offsets[12] = {0, 7, 2, 9, 4, 11, 5, 10, 3, 8, 1, 6}; // Circle of fifths: semitone offset for each key’s root note relative to C: C, G, D, A, E, B, F, Bb, Eb, Ab, Db, Gb
const int8_t key_signatures[12] = {0, 1, 2, 3, 4, 5, 1, 2, 3, 4, 5, 6}; // Number of sharps or flats for each key: Sharps for C, G, D, A, E, B; flats for F, Bb, Eb, Ab, Db, Gb
const int8_t sharp_notes[6][6] = { // Notes affected by sharps in each key, in hardware order (B, E, A, D, G, C, F)
  {BTN_F},          // 1 sharp: F#
  {BTN_F, BTN_C},   // 2 sharps: F#, C#
  {BTN_F, BTN_C, BTN_G}, // 3 sharps: F#, C#, G#
  {BTN_F, BTN_C, BTN_G, BTN_D}, // 4 sharps: F#, C#, G#, D#
  {BTN_F, BTN_C, BTN_G, BTN_D, BTN_A}, // 5 sharps: F#, C#, G#, D#, A#
  {BTN_F, BTN_C, BTN_G, BTN_D, BTN_A, BTN_E} // 6 sharps: F#, C#, G#, D#, A#, E#
};
const int8_t flat_notes[6][6] = { // Notes affected by flats in each key, in hardware order (B, E, A, D, G, C, F)
  {BTN_B},          // 1 flat: Bb
  {BTN_B, BTN_E},   // 2 flats: Bb, Eb
  {BTN_B, BTN_E, BTN_A}, // 3 flats: Bb, Eb, Ab
  {BTN_B, BTN_E, BTN_A, BTN_D}, // 4 flats: Bb, Eb, Ab, Db
  {BTN_B, BTN_E, BTN_A, BTN_D, BTN_G}, // 5 flats: Bb, Eb, Ab, Db, Gb
  {BTN_B, BTN_E, BTN_A, BTN_D, BTN_G, BTN_C} // 6 flats: Bb, Eb, Ab, Db, Gb, Cb
};

float c_frequency = 130.81;                      // for C3
uint8_t chord_octave_change=4;
uint8_t harp_octave_change=4;
uint8_t chord_frame_shift=0;
uint8_t transpose_semitones=0;                       // to use to transpose the instrument, number of semitones
uint8_t (*current_chord)[7] = &major;            // the array holding the current chord
uint8_t current_chord_notes[7];                  // the array for the note calculation within the chord, calculate 7 of them for the arpeggiator mode
uint8_t current_applied_chord_notes[7];          // the array for the note calculation within the chord
uint8_t current_harp_notes[12];                  // the array for the note calculation within the string

//>>SWITCHING LOGIC GLOBAL VARIABLES<<
int8_t current_line = -1;      // holds the current selected line of button, -1 if nothing is on
int8_t fundamental = 0;        // holds the value of the last selected line, hence the fundamental
uint8_t slash_value = 0;       // stores the "slash", ie when a different alternative note is selected
bool slash_chord = false;      // flag for when a slashed chord is currently activated
bool button_pushed = false;    // flag for when any button has been pushed during the main loop
bool trigger_chord = false;    // flag to trigger the enveloppe of the chord
bool sharp_active = false;     // flag for when the sharp is active
bool flat_button_modifier= false; //flag to set the modifier to flat instead of sharp
bool continuous_chord = false; // wether the chord is held continuously. Controlled by the "hold" button
bool rythm_mode = false;
bool barry_harris_mode = false;
IntervalTimer note_timer[4]; // timers for delayed chord enveloppe
bool inhibit_button=false;

//>>SWITCHING LOGIC PARAMETERS<<
uint8_t note_slash_level = 0;     // the level we are replacing in the chord when slashing (usually the fundamental)
bool retrigger_chord = true;      // wether or not to retrigger the enveloppe when the chord is switched within current line (including when selecting slash chord)
bool change_held_strings = false; // to control wether hold strings change with chord:
bool chromatic_harp_mode = false; // to switch the harp to chromatic mode
//>>SYSEX PARAMETERS<<
// SYSEX midi message are used to control up to 256 synthesis parameters.
const uint16_t parameter_size = 256;
const uint8_t preset_number = 12;
int16_t default_bank_sysex_parameters[preset_number][parameter_size] = {
  {0,0,50,50,512,512,512,0,0,0,192,100,49,100,184,100,157,100,0,0,0,0,0,0,43,0,50,37,38,67,0,0,0,0,0,0,0,0,0,0,0,16,0,8,8,12,42,1171,1,423,20,70,3,35,83,59,2658,1,0,0,0,0,0,0,0,1,1,1,100,1,1,0,1,1,1,1,14,0,0,70,0,0,0,100,0,6,0,0,755,195,23,61,29,0,0,0,0,162,0,2,0,0,0,0,0,0,0,0,0,0,0,0,0,0,0,0,0,0,0,0,2,13,8,100,16,0,200,0,0,50,0,50,18,32,50,0,0,10,66,353,65,995,1,569,16,141,32,83,28,48,54,1,0,0,0,56,0,389,0,20,0,0,0,0,1,1,1,0,1,1,0,1,1,1,1,0,0,0,70,0,0,0,100,0,64,0,0,80,16,4,94,753,474,70,5,100,100,100,2,0,0,0,0,0,0,0,0,0,0,0,0,0,0,0,0,0,0,0,0,0,16,0,6,6,32,0,6,0,16,0,6,6,32,0,6,0,0,0,0,0,0,0,0,0,0,0,0,0,0,0,0,0,0,0,0,0},
  {0,0,50,50,512,512,512,0,0,0,194,100,85,100,60,100,61,100,0,0,10,1,0,0,0,0,0,0,0,100,0,0,0,0,0,0,0,0,0,0,4,25,8,3,29,18,65,488,3,159,25,70,5,18,4,26,6,1,77,0,587,32,0,390,0,76,1,1,100,1,1,68,17,14,22,20,0,340,1682,70,48,0,0,100,18,54,0,0,800,70,57,100,100,0,0,0,0,199,0,2,0,0,0,0,0,0,0,0,0,0,0,0,0,0,0,0,0,0,0,0,4,7,0,100,0,0,100,6,8,200,2,50,36,75,50,28,0,3,1,1,80,1218,2,1659,38,114,19,8,32,80,1,1,0,30,0,0,0,0,0,0,0,24,0,3,1,1,1,100,1,1,100,1,1,1,1,31,0,0,70,0,0,0,100,0,33,2,1,162,16,4,100,100,1436,118,100,50,32,107,2,0,0,0,0,0,0,0,0,0,0,0,0,0,0,0,0,0,0,0,0,0,7,0,0,0,13,0,4,0,7,0,0,2,13,0,0,2,0,0,0,0,0,0,0,0,0,0,0,0,0,0,0,0,0,0,0,0},
  {0,0,50,50,512,512,512,0,0,0,192,100,49,100,184,100,157,100,0,0,30,0,1,1,87,33,62,12,80,67,0,0,0,0,0,0,0,0,0,0,0,6,3,8,8,12,42,1855,1,42,20,217,3,35,83,59,2658,1,185,0,282,14,0,247,11,1,1,1,100,1,1,0,1,1,1,1,14,0,0,70,0,0,0,100,0,23,0,0,755,195,82,61,29,0,0,0,0,162,0,2,0,0,0,0,0,0,0,0,0,0,0,0,0,0,0,0,0,0,0,0,1,13,0,100,23,8,200,0,0,50,0,50,18,32,50,0,0,10,66,353,44,1452,1,569,16,141,32,83,28,48,54,1,0,698,82,56,0,579,0,28,0,0,0,0,1,1,1,0,1,1,100,1,1,1,1,0,0,0,70,0,0,0,100,0,100,0,0,80,16,4,94,753,474,70,5,100,100,100,2,0,0,0,0,0,0,0,0,0,0,0,0,0,0,0,0,0,0,0,0,0,16,0,6,6,32,0,6,0,16,0,6,6,32,0,6,0,0,0,0,0,0,0,0,0,0,0,0,0,0,0,0,0,0,0,0,0},
  {0,0,50,50,512,512,512,0,0,0,196,76,92,100,184,100,85,100,0,0,60,0,1,0,14,0,0,0,42,46,0,0,0,0,0,0,0,0,0,0,3,10,8,11,42,30,61,2137,1,106,22,140,4,35,83,24,1956,1,139,0,282,0,0,247,10,1,1,1,100,1,1,0,1,1,1,1,0,0,0,70,0,0,0,100,0,57,0,1,858,70,66,100,100,0,0,0,0,127,0,2,0,0,0,0,0,0,0,0,0,0,0,0,0,0,0,0,0,0,0,0,0,17,8,200,11,0,134,10,0,100,7,50,59,15,50,0,15,10,10,45,61,1489,1,652,16,84,32,21,15,33,19,1,0,490,0,109,0,252,0,8,0,244,1,49,1,1,1,15,1,1,100,1,1,1,1,26,479,1931,70,0,50,0,100,40,78,21,0,162,16,4,100,1000,639,140,100,47,100,85,2,0,0,0,0,0,0,0,0,0,0,0,0,0,0,0,0,0,0,0,0,0,65,0,12,0,0,12,0,0,65,0,6,0,0,6,0,0,0,0,0,0,0,0,0,0,0,0,0,0,0,0,0,0,0,0,0,0},
  {0,0,50,50,512,512,512,0,0,0,146,100,76,100,85,79,184,100,0,0,110,0,0,0,57,0,0,0,67,58,0,0,0,0,0,0,0,0,0,0,0,6,8,8,65,12,38,1855,5,57,24,152,3,35,83,59,2658,6,137,0,640,8,0,247,11,1,1,1,100,1,1,131,4,116,3,1,11,424,1360,70,46,0,0,100,60,85,0,0,996,125,82,61,71,0,0,0,0,90,0,2,0,0,0,0,0,0,0,0,0,0,0,0,0,0,0,0,0,0,0,0,0,20,0,100,23,0,200,15,8,100,0,50,0,18,50,0,0,2,293,17,44,1012,1,10,33,141,32,83,28,67,239,1,0,0,0,287,0,579,0,0,0,366,0,35,5,52,12,0,1,1,100,1,1,1,1,16,0,0,70,0,0,0,100,0,50,0,0,184,16,4,100,100,657,70,86,100,100,95,2,0,0,0,0,0,0,0,0,0,0,0,0,0,0,0,0,0,0,0,0,0,7,0,0,2,4,2,15,0,2,2,6,2,6,15,0,0,0,0,0,0,0,0,0,0,0,0,0,0,0,0,0,0,0,0,0,0},
  {0,0,50,50,512,512,512,0,0,0,192,60,47,56,159,100,157,100,0,0,138,1,0,0,0,0,0,0,27,74,0,0,0,0,0,0,0,0,0,0,4,14,11,3,29,18,65,1102,3,302,11,70,5,18,4,26,6,1,38,0,516,16,0,0,0,76,1,1,100,1,1,68,17,14,22,20,0,340,1682,70,48,0,0,100,18,58,0,0,800,70,43,100,100,0,0,0,0,200,0,2,0,0,0,0,0,0,0,0,0,0,0,0,0,0,0,0,0,0,0,0,4,10,11,100,9,0,200,4,8,200,0,50,36,75,50,0,0,3,1,1,80,1855,2,769,15,114,19,8,32,80,1,1,0,30,0,11,0,467,0,35,0,24,0,3,1,1,1,100,1,1,100,1,1,1,1,0,341,2164,70,54,0,0,100,36,42,0,1,80,16,4,100,20,2101,70,100,6,22,55,2,0,0,0,0,0,0,0,0,0,0,0,0,0,0,0,0,0,0,0,0,0,1,2,4,8,17,0,12,0,1,2,4,8,16,6,0,1,0,0,0,0,0,0,0,0,0,0,0,0,0,0,0,0,0,0,0,0},
  {0,0,50,50,512,512,512,0,0,0,192,100,61,100,130,100,83,100,0,0,175,0,0,0,0,0,0,0,0,35,0,0,0,0,0,0,0,0,0,0,0,12,9,11,1,1,70,2141,1,383,17,302,101,103,34,30,1,12,0,0,367,17,0,363,5,1,1,1,86,1,1,0,1,1,1,1,8,0,0,70,0,0,0,100,0,33,50,0,5000,70,100,0,0,0,0,0,0,90,0,2,0,0,0,0,0,0,0,0,0,0,0,0,0,0,0,0,0,0,0,0,5,9,9,200,13,6,99,6,0,50,27,50,50,50,50,0,0,345,1,1,80,800,32,2200,0,70,1,1,1,100,1,1,0,30,0,0,0,166,0,6,0,0,0,0,1,1,1,0,1,1,100,1,1,1,1,0,0,0,70,0,0,0,100,0,59,100,0,80,16,4,100,100,2366,70,100,40,23,57,2,0,0,0,0,0,0,0,0,0,0,0,0,0,0,0,0,0,0,0,0,0,1,0,4,4,16,16,12,0,1,6,8,6,0,6,0,1,0,0,0,0,0,0,0,0,0,0,0,0,0,0,0,0,0,0,0,0},
  {0,0,50,50,512,512,512,0,0,0,146,100,76,100,85,79,184,100,0,0,220,0,0,0,0,0,0,86,55,63,0,0,0,0,0,0,0,0,0,0,0,6,8,8,65,12,38,1855,5,57,24,152,3,35,83,59,2658,6,137,0,640,8,0,247,11,1,1,1,100,1,1,131,4,116,3,1,11,424,1360,70,46,0,0,100,60,84,0,0,996,125,82,61,71,0,0,0,0,90,0,2,0,0,0,0,0,0,0,0,0,0,0,0,0,0,0,0,0,0,0,0,0,20,0,100,23,0,200,15,8,100,0,50,0,18,50,0,0,2,293,17,44,1012,1,10,33,141,32,83,28,67,239,1,0,0,0,287,0,579,0,0,0,366,0,35,5,52,12,0,1,1,100,1,1,1,1,16,0,0,70,0,0,0,100,0,50,0,0,184,16,4,100,100,657,70,86,100,100,95,2,0,0,0,0,0,0,0,0,0,0,0,0,0,0,0,0,0,0,0,0,0,7,0,0,2,4,2,15,0,2,2,6,2,6,15,0,0,0,0,0,0,0,0,0,0,0,0,0,0,0,0,0,0,0,0,0,0},
  {0,0,50,50,512,512,512,0,0,0,196,100,47,56,159,100,157,100,0,0,253,1,0,0,0,0,0,0,0,59,0,0,0,0,0,0,0,0,0,0,4,15,11,3,29,18,65,1102,3,302,11,70,5,18,4,26,6,1,38,0,516,16,0,0,12,76,1,22,100,1,1,68,17,14,22,20,0,340,1682,70,48,0,0,100,18,58,0,0,800,70,43,100,100,0,0,0,0,158,0,2,0,0,0,0,0,0,0,0,0,0,0,0,0,0,0,0,0,0,0,0,4,10,0,100,9,0,200,4,8,200,0,50,36,75,50,0,0,3,1,1,80,1855,2,769,15,114,19,8,32,80,1,1,0,30,0,11,0,467,0,22,0,24,0,3,1,1,1,100,1,1,100,1,1,1,1,0,341,2164,70,54,0,0,100,36,42,0,1,80,16,4,100,20,532,70,100,6,82,96,2,0,0,0,0,0,0,0,0,0,0,0,0,0,0,0,0,0,0,0,0,0,1,2,4,8,17,0,12,0,1,2,4,8,16,6,0,1,0,0,0,0,0,0,0,0,0,0,0,0,0,0,0,0,0,0,0,0},
  {0,0,50,50,512,512,512,0,0,0,149,69,76,100,85,79,184,100,0,0,266,0,0,0,0,0,0,0,65,70,0,0,0,0,0,0,0,0,0,0,0,5,0,8,65,12,38,1855,5,57,24,152,3,35,83,59,2658,6,137,0,640,8,0,247,11,1,1,1,100,1,1,131,4,116,3,1,0,424,1360,70,46,0,0,100,60,81,0,0,996,125,82,61,71,0,0,0,0,108,0,2,0,0,0,0,0,0,0,0,0,0,0,0,0,0,0,0,0,0,0,0,1,20,12,100,23,0,200,15,8,100,0,50,45,17,0,0,0,2,293,17,44,1012,1,10,33,141,32,83,28,67,239,1,0,0,0,287,0,579,0,0,0,366,0,35,5,52,12,0,1,1,100,1,1,1,1,16,0,0,70,0,0,0,100,0,50,0,0,184,16,4,100,100,857,70,42,100,100,158,2,0,0,0,0,0,0,0,0,0,0,0,0,0,0,0,0,0,0,0,0,0,7,0,0,2,4,2,15,0,2,2,6,2,6,15,0,0,0,0,0,0,0,0,0,0,0,0,0,0,0,0,0,0,0,0,0,0},
  {0,0,50,50,512,512,512,0,0,0,192,55,61,100,184,100,85,100,0,0,310,0,0,0,86,0,56,87,37,60,0,0,0,0,0,0,0,0,0,0,4,15,12,36,42,30,59,1410,1,30,33,140,4,35,83,24,615,1,94,0,282,15,0,247,0,1,1,1,100,1,1,0,1,1,1,1,0,0,0,70,0,0,0,100,0,40,0,1,858,70,46,100,82,0,0,0,0,124,0,2,0,0,0,0,0,0,0,0,0,0,0,0,0,0,0,0,0,0,0,0,1,16,8,200,18,0,134,21,0,200,2,50,59,15,50,18,15,10,66,43,35,711,1,271,16,84,32,83,733,31,54,1,0,698,0,220,0,252,0,8,0,244,1,49,1,1,1,15,1,1,100,1,1,1,1,26,479,1931,70,0,50,0,100,34,75,0,0,162,16,4,100,1000,1889,116,49,100,42,129,2,0,0,0,0,0,0,0,0,0,0,0,0,0,0,0,0,0,0,0,0,0,65,0,12,0,0,12,0,0,65,0,6,0,0,6,0,0,0,0,0,0,0,0,0,0,0,0,0,0,0,0,0,0,0,0,0,0},
  {0,0,50,50,512,512,512,0,0,0,194,100,85,100,60,100,61,100,0,0,340,1,0,0,0,0,0,0,0,62,0,0,0,0,0,0,0,0,0,0,4,25,3,3,29,18,65,488,3,159,25,70,5,18,4,26,40,1,77,0,587,32,0,715,11,76,1,1,100,1,1,68,17,14,22,20,17,340,1682,70,48,0,0,100,18,54,0,0,800,70,57,100,100,0,0,0,0,199,0,2,0,0,0,0,0,0,0,0,0,0,0,0,0,0,0,0,0,0,0,0,1,3,1,100,0,0,100,6,8,200,2,50,36,75,50,28,0,3,1,1,80,1218,2,706,38,114,19,8,32,80,1,1,0,30,0,0,0,0,0,0,0,24,0,3,1,1,1,100,1,1,100,1,1,1,1,31,0,0,70,0,0,0,100,0,33,2,1,162,16,4,100,100,678,118,100,50,32,168,2,0,0,0,0,0,0,0,0,0,0,0,0,0,0,0,0,0,0,0,0,0,7,0,0,0,13,0,4,0,7,0,0,2,13,0,0,2,0,0,0,0,0,0,0,0,0,0,0,0,0,0,0,0,0,0,0,0}
};
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
void loop() {
  //>>Looking for incoming midi message
  if (usbMIDI.read()) {
    processMIDI();
  }
  //Checking if the sysex is still connected 
  if (sysex_controler_connected && (USB1_PORTSC1,7)){
    sysex_controler_connected=false;
  }
  //>>Updating the debouncers
  hold_button.set(digitalRead(HOLD_BUTTON_PIN));
  up_button.set(digitalRead(UP_PGM_PIN));
  down_button.set(digitalRead(DOWN_PGM_PIN));
  LBO_flag.set(digitalRead(BATT_LBO_PIN));
  chord_matrix.update(chord_matrix_array);
  //>>handling low battery blink indicator
  uint8_t LBO_transition = LBO_flag.read_transition();
  if (LBO_transition == 1) {
    led_blinking_flag=true;
  } else if (LBO_transition == 2) {
    led_blinking_flag=false;
    set_led_color(bank_led_hue, 1.0, 1-led_attenuation); // turn the led to the bank color
  }

   if (led_blinking_flag) {
    set_led_color(bank_led_hue, 1.0, 0.6+0.4*sin(color_led_blink_val));
    color_led_blink_val+=0.005;
  } 


  //>>Handlind the hold button functions
  uint8_t hold_transition = hold_button.read_transition();
  if (hold_transition == 2) {
    if (!rythm_mode) {
      Serial.println("Switching mode");
      continuous_chord = !continuous_chord;
      analogWrite(RYTHM_LED_PIN, 255 * continuous_chord);
      if(current_line==-1){ //if no button is currently pushed, we want to trigger when it happens in continuous chord mode. 
        trigger_chord = true;
      }
    } else {
      //>>push tempo management
      if (since_last_button_push > 100 && since_last_button_push < 2000) {  // check that we are inside the BPM range
        rythm_bpm = (rythm_bpm*5.0 + 60 * 1000 / (since_last_button_push)) / 6.0; // we push for full note, with smoothing
        Serial.print("Updating the BPM to:");
        Serial.println(rythm_bpm);
        recalculate_timer();        
        if (current_long_period) {
          rythm_timer.update(long_timer_period);
        } else {
          rythm_timer.update(short_timer_period);
        }

      }
    }
    since_last_button_push = 0;
  }
  //>>Handling the long hold to switch to rythm mode
  if (hold_transition == 1) {
    if (since_last_button_push > 800) {
      Serial.println("Long push, switching rythm mode");
      rythm_mode = !rythm_mode;
      continuous_chord = false;
      analogWrite(RYTHM_LED_PIN, 255 * continuous_chord);
      if (rythm_mode) {
        rythm_current_step=0;
        Serial.println("Starting rythm timers");
        rythm_timer.priority(254);
        rythm_timer.begin(rythm_tick_function, short_timer_period);
        rythm_timer_running = true;
        rythm_timer.update(long_timer_period);
         current_long_period = true;
      }else{
        Serial.println("Stopping rythm timers");
        rythm_timer.end();
        rythm_timer_running = false;
      }
    }
  }
  //>>Handling the preset change interface
  if (up_button.read_transition() > 1) {
    Serial.println("Switching to next preset");
    if(!sysex_controler_connected && flag_save_needed){
      save_config(current_bank_number, false); // saving to remember alternate pot position when not connnected
    }    current_bank_number = (current_bank_number + 1) % 12;
    load_config(current_bank_number);
  }
  if (down_button.read_transition() > 1) {
    Serial.println("Switching to last preset");
    if(!sysex_controler_connected && flag_save_needed){
      save_config(current_bank_number, false); // saving to remember alternate pot position when not connnected
    }
    current_bank_number = (current_bank_number - 1);
    if (current_bank_number == -1) {
      current_bank_number = 11;
    }
    load_config(current_bank_number);
  }

  //>>Handling the turning off of notes in rythm mode (mandatory because we are missing one timer to do it cleanly)
  if(rythm_mode){
    for (int i = 0; i < 4; i++) {
      if(note_off_timing[i]>note_pushed_duration && chord_envelope_array[i]->isSustain()){
        chord_vibrato_envelope_array[i]->noteOff();
        chord_vibrato_dc_envelope_array[i]->noteOff();
        chord_envelope_array[i]->noteOff();
        chord_envelope_filter_array[i]->noteOff();
        if(chord_started_notes[i]!=0){
          usbMIDI.sendNoteOff(chord_started_notes[i],chord_release_velocity,1,chord_port);
          chord_started_notes[i]=0;
        }
      }
    }
  }

  //>>Handling the potentiometer mode
  bool alternate = chord_matrix_array[0].read_value(); // use the sharp as potentiometer alt selection
  flag_save_needed=chord_pot.update_parameter(alternate)||flag_save_needed;
  flag_save_needed=harp_pot.update_parameter(alternate)||flag_save_needed;
  flag_save_needed=mod_pot.update_parameter(alternate)||flag_save_needed;

  //>>Handling of chords logic
  // If not button is active in touch mode, then turn everything off
  //if more than three buttons in a line are on, we don't take it on
  if (!continuous_chord && !rythm_mode) {
    bool one_button_active = false;
    int line_accumulator[3]={0,0,0};
    for (int i = 1; i < 22; i++) {
      bool active=chord_matrix_array[i].read_value();
      one_button_active = one_button_active || active;
      if(active){
        line_accumulator[i%3]+=1;
      }
    }
    if(line_accumulator[0]>2 ||line_accumulator[1]>2 || line_accumulator[2]>2){
      current_line=-1;
      inhibit_button=true;
    }
    if (!(one_button_active)) { 
      inhibit_button=false; //we can resume working
      AudioNoInterrupts();
      for (int i = 0; i < 4; i++) {
        if(  chord_envelope_array[i]->isSustain()){
          chord_vibrato_envelope_array[i]->noteOff();
          chord_vibrato_dc_envelope_array[i]->noteOff();
          chord_envelope_array[i]->noteOff();
          chord_envelope_filter_array[i]->noteOff();
          if(chord_started_notes[i]!=0){
            usbMIDI.sendNoteOff(chord_started_notes[i],chord_release_velocity,1,chord_port);
            chord_started_notes[i]=0;
          }

        }
      }
      AudioInterrupts();
    }
  }
  // If there is a line currently active, then start the update logic
  if (current_line >= 0) {
    fundamental = current_line; // this is our active line
    slash_chord = false;
    // let's check if we have a slashed chord and if that's the case, which
    for (int i = 1; i < 22; i++) {
      bool value = chord_matrix_array[i].read_value();
      if (value) {
        int slash_line = (i - 1) / 3;
        if (slash_line != current_line) {
          slash_chord = true;
          slash_value = slash_line;
        }
      }
    }
    // detect which buttons are active within our line
    bool button_maj = chord_matrix_array[1 + current_line * 3].read_value();
    bool button_min = chord_matrix_array[2 + current_line * 3].read_value();
    bool button_seventh = chord_matrix_array[3 + current_line * 3].read_value();
    if (!(button_maj || button_seventh || button_min)) {
      current_line = -1; // if no button is, then line is no more active. we get out of that loop
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

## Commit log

2024-12-26 Additional 3D files, plus
    [BOM-Keymaster PCB.csv, BOM-touch_zone.csv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]
2024-12-26 Added ressources, fixed typo
    [Keymaster PCB-CuBottom.gbr, Keymaster PCB-CuTop.gbr, Keymaster PCB-EdgeCuts.gbr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]
2024-12-26 Need to clean file uploaded
    [BOM-Keymaster PCB.csv, BOM-touch_zone.csv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]
2024-12-30 Small updates and file cleaning
    [all_parts.FCStd, buttons.stl, full_3D_script.scad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]
2025-01-17 Modified firmware for the 10 minichords: better preset, and fixed reverb noise issue
    [MiniChord-User_led_clearance.dxf, MiniChord-User_top_component_clearance.dxf, render_v11_bottom.scad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]
2025-01-17 Updated documentations for new enclosure that necessitates less manual intervention and cutting. Also fixed an error pointed out by Zach
2025-02-03 Forgot to reactivate the low battery blinking
2025-02-07 Added Kicad template for custom touch zone
    [Keymaster PCB-CuBottom.gbr, Keymaster PCB-CuTop.gbr, Keymaster PCB-EdgeCuts.gbr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]
2025-02-07 A bit of housekeeping
    [Keymaster PCB-CuBottom.gbr, Keymaster PCB-CuTop.gbr, Keymaster PCB-EdgeCuts.gbr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]
2025-02-09 Update on the webpage to reflect the current status of the projetc (production TBD)
2025-02-14 at the request of instalinu, added an electronic BOM with MFR#
    [electronics_BOM.csv]
2025-02-16 Added battery check at startup plus slight deepening of the screw holes
    [render_v11_bottom.scad]
2025-02-17 Changed the touch zone size following Hainbach's feedback
    [touch_zone-CuBottom.gbr, touch_zone-CuTop.gbr, touch_zone-EdgeCuts.gbr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]
2025-04-11 PCB update to add the diodes
    [MiniChord-CuBottom.gbr, MiniChord-CuIn1.gbr, MiniChord-CuIn2.gbr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]
2025-05-06 Updated PNG of schematics
2025-05-13 Update to reflect the fact that when testing led can be both color
2025-06-06 Solve for issue #23 and #22. Had to add a version identifier to avoid user wondering why some control would not work for their version of the firmware.
    [main.cpp]
2025-06-06 Solved issue #21. Could not preserve preset compatibility, need to add a step to wipe preset after software update
    [main.cpp]
2025-06-08 Added documentation on the arrow per #28, plus limited the range of the retrigger release in the frontend per #31 until I can find a better fix
    [main.cpp]
2025-06-13 Fix for error #29, detecting the loss of USB connection
    [main.cpp]
2025-06-16 Adds Barry Harris mode: option to change major to M6, minor to m6, diminished to full-dim. Fixes generate.py: missing href to minichordcontroller.js and directory reference for index.js
    [main.cpp]
2025-06-16 Fixed for retrocompatibility plus added forgotten JSON modifications
    [main.cpp]
2025-06-24 add 3d files for keycaps
    [keycap.stp]
2025-07-08 Fixes my presets; my custom firmwareand/or minicontrol experiment added pitch bends unintentionally. I'll be more careful in the future!
2025-07-10 Adds Chord Frame Shift, with 2D root_button array. Firmware.hex, JSON change, sysex_handler change, address 18
2025-07-14 Fixed scale_lengths array for minor pentatonic
    [main.cpp]
